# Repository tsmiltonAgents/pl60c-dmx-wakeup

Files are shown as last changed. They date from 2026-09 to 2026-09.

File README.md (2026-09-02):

# PL60C DMX wake-up lamp controller

A small ESP32-S3 board that drives the wired DMX512 input of a **Neewer PL60C** panel light so the
light can be ramped up slowly in the morning (sunrise alarm). Rev A, 2026-09-02.

Everything in this repository is generated by scripts (`./build.sh`): schematic, PCB, autorouting,
design-rule checks, Gerbers, and the JLCPCB BOM / pick-and-place files. The design passes KiCad ERC and
DRC with zero errors, the schematic and PCB netlists are cross-checked against the single source of
truth (`hw/design.py`), and every part number has been verified in stock on LCSC/JLCPCB.

| | |
|---|---|
| Board | 80 x 54 mm, 2 layers, 1.6 mm FR-4, all parts on the top side |
| MCU | ESP32-S3-WROOM-1-N16R8 (Wi-Fi + BLE, native USB) |
| DMX out | 5-pin XLR female (Neutrik NC5FAH) **and** a 3-way screw terminal for a pigtail |
| Power | USB-C, 5 V, 1 A resettable fuse, 3.3 V LDO |
| UI | RESET, BOOT, USER buttons, WS2812B RGB status LED, magnetic buzzer (alarm fallback) |
| Extras | I2C/GPIO expansion header (RTC, light sensor), UART0 header |
| Files to order | `production/pl60c_dmx_gerbers.zip`, `production/pl60c_dmx_bom_jlcpcb.csv`, `production/pl60c_dmx_cpl_jlcpcb.csv` |
| Mini variant | 38.5 x 29 mm, 4 layers, both sides, same circuit and pin map: see section 8 and `production_mini/` |

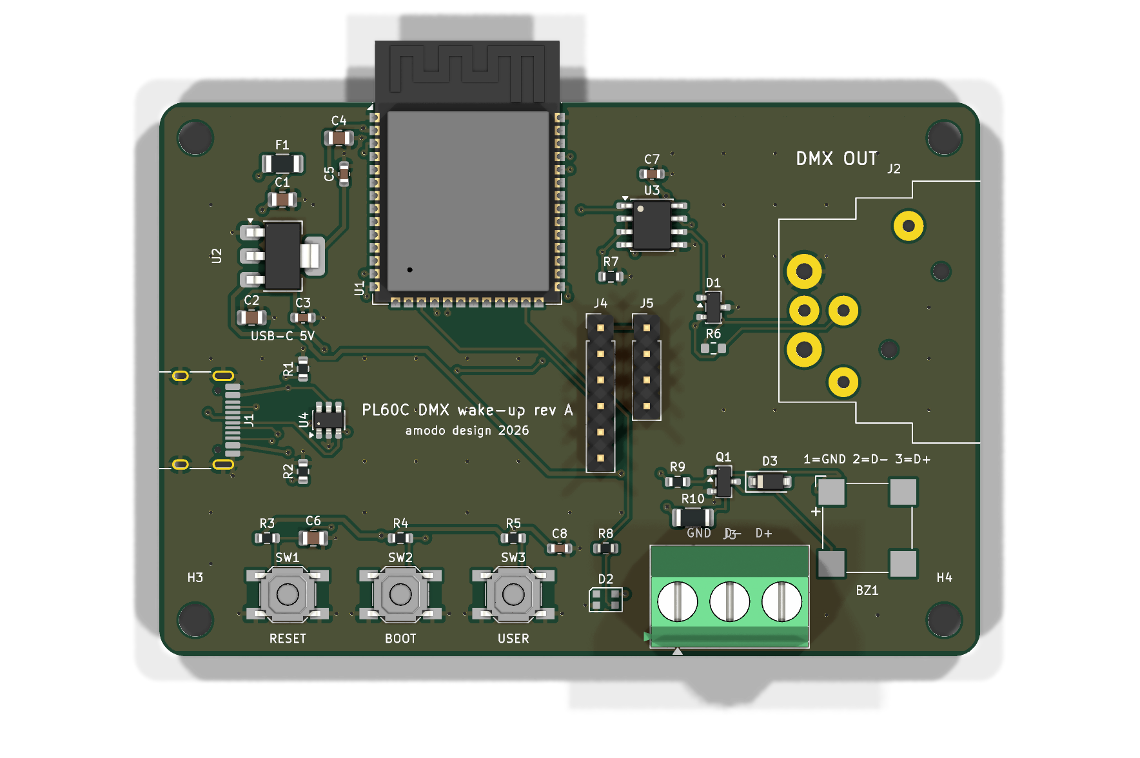
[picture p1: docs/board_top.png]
Board top


Status: **designed, reviewed and verified in software, not yet manufactured or bench-tested.** Read the
"Before you order" section and `docs/REVIEW.md` (design review: 3 wiring/spec bugs found and fixed).

---

## 1. How the light is controlled

### 1.1 The PL60C's DMX port (verified from Neewer's manual and DMX chart)

* Connectors on the bottom edge of the lamp head: `DMX-IN` = **5-pin XLR male** panel socket,
  `DMX-OUT` = 5-pin XLR female (pass-through for daisy-chaining).
* Pinout: pin 1 = signal common (0 V), pin 2 = Data−, pin 3 = Data+, pins 4 and 5 unused.
* Enable DMX on the light: long-press MODE/MENU, set `DMX ON/OFF` = ON, then `DMX ADDR` (001–512, default 1).
* On loss of the DMX signal the light **holds the last look** (no timeout). The controller must therefore
  keep streaming frames; when you want the light off, send intensity 0 rather than stopping the stream.
* No RDM support is documented. The port is not documented as isolated.

This board is the DMX **transmitter**, so it has a 5-pin XLR **female** socket (ANSI E1.11 convention).
A normal 5-pin DMX cable (male–female) goes from this board to the light's `DMX-IN`.

### 1.2 PL60C channel map (one fixed personality)

Channel numbers are relative to the DMX start address `n` set on the light. Channel `n` selects the mode,
`n+1` is always intensity, the rest depend on the mode. The FX mode uses up to 9 channels, so treat the
light as a 9-channel fixture.

| ch n value | Mode | n+1 | n+2 | n+3 | n+4 … n+8 |
|---|---|---|---|---|---|
| 0–31 | **CCT** | Intensity 0–100 % | Colour temperature 2500–10000 K | G/M −50…+50 | – |
| 32–63 | HSI | Intensity | Hue 0–360° | Saturation 0–100 % | – |
| 64–95 | FX | Intensity | Effect select | effect parameters | effect parameters |
| 96–127 | GEL | Intensity | Gel brand | Gel index | – |
| 128–159 | RGBCW | Intensity | Red | Green | Blue, Cool white, Warm white |
| 160–191 | XY | Intensity | x | y | – |

For a sunrise, CCT mode is the natural choice: ramp `n+1` from 0 to the target and, if you like, sweep
`n+2` from warm (2500 K) towards neutral as the intensity rises. Sources are listed at the end.

### 1.3 DMX512 on the wire

DMX512 is EIA-485 at 250 kbit/s, 8 data bits, no parity, 2 stop bits. A frame is: BREAK (≥ 92 µs, use
176 µs) → MARK-AFTER-BREAK (≥ 12 µs) → start code 0x00 → up to 512 slot bytes, then repeat at roughly
40–44 Hz. Data+ (pin 3) is the RS-485 **A** line, Data− (pin 2) is **B**, pin 1 is the common. A 120 Ω
terminator belongs only at the far end of the cable (the last fixture), never at the transmitter.

---

## 2. Hardware design

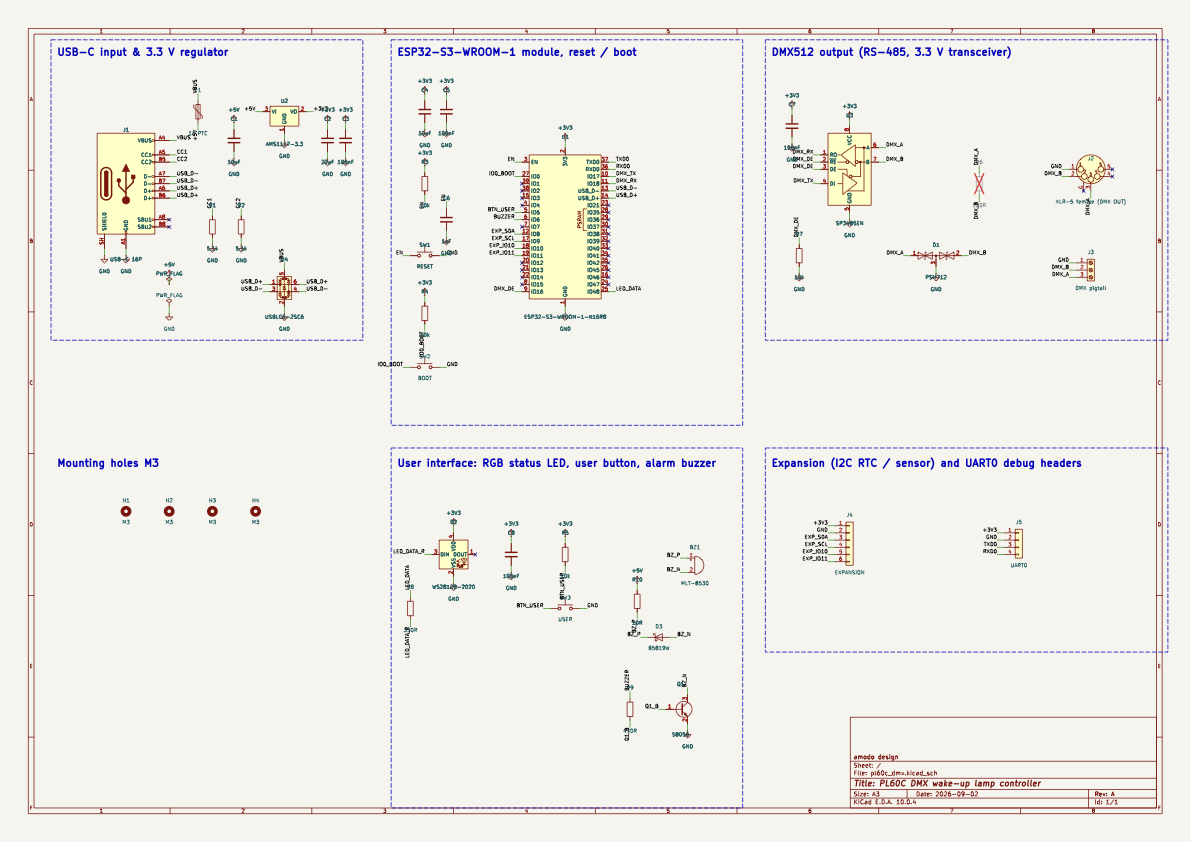
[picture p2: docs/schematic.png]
Schematic


Full-size PDF: `production/pl60c_dmx_schematic.pdf`.

### 2.1 Blocks

**USB-C input and 3.3 V rail.** 16-pin USB-C receptacle (HRO TYPE-C-31-M-12) with 5.1 kΩ CC pull-downs
so any USB-C charger or host supplies 5 V. A 1 A hold / 1.8 A trip PTC (F1) protects the board, a
USBLC6-2SC6 (U4) clamps ESD on D+/D−/VBUS, and an AMS1117-3.3 (U2, 1 A) makes 3.3 V with 10 µF on both
sides. Budget: ESP32-S3 Wi-Fi peaks ≈ 0.5 A, buzzer ≈ 0.1 A average, LED < 60 mA.

**ESP32-S3-WROOM-1-N16R8 (U1).** 16 MB flash, 8 MB PSRAM, on-module PCB antenna. The antenna end of the
module hangs 6 mm past the top board edge, which is Espressif's preferred placement (no copper anywhere
near the antenna). USB D+/D− go straight to GPIO20/GPIO19: the S3's built-in USB-Serial/JTAG gives
programming, console and debugging with no bridge chip. EN has the standard 10 kΩ + 1 µF reset delay and
the RESET button; GPIO0 has a 10 kΩ pull-up and the BOOT button (hold BOOT, tap RESET to force the
ROM downloader, or just use `esptool` over USB which does it automatically).

**DMX transmitter (U3, SP3485EN).** 3.3 V RS-485 half-duplex transceiver, pin-compatible with MAX3485.
DI ← GPIO17 (UART TX), RO → GPIO18 (UART RX), DE and /RE tied together to GPIO16 with a 10 kΩ pull-down,
so the line is only driven once firmware asserts DE (keeps the bus quiet during boot/flash). A → XLR
pin 3 (Data+), B → XLR pin 2 (Data−), XLR pin 1 → GND. A PSM712 asymmetric TVS array (D1, +12 V / −7 V,
the RS-485 standard part) clamps surges on both lines. R6 (120 Ω) is fitted **only** if you ever want this
board to terminate a line; it is marked DNP and JLCPCB will not place it. The same three signals are on
screw terminal J3 (GND, D−, D+) so you can wire a cable pigtail instead of using the XLR.

**User interface.** WS2812B-2020-V6 RGB LED (D2) on GPIO48 through 330 Ω, powered from 3.3 V (the V6
silicon is specified for 3.3 V supply, VIH = 0.55 VDD). USER button on GPIO5 with a 10 kΩ pull-up
(snooze / manual on). Magnetic buzzer BZ1 (MLT-8530, passive, 2.7 kHz resonant, 16 Ω) driven from the
5 V rail through a 10 Ω series resistor (R10, limits the coil to its 3.6 V rating) by an S8050 NPN (Q1,
SOT-23, base via 470 Ω from GPIO6) with a B5819W Schottky flyback diode (D3) across the coil.

**Expansion.** J4: 3V3, GND, GPIO8 (SDA), GPIO9 (SCL), GPIO10, GPIO11 (e.g. a DS3231 RTC or an ambient
light sensor). J5: 3V3, GND, GPIO43 (TXD0), GPIO44 (RXD0). Four M3 mounting holes.

### 2.2 Pin map (also in `firmware/pins.h`)

| Function | GPIO | Notes |
|---|---|---|
| DMX TX (SP3485 DI) | 17 | UART1 TX |
| DMX RX (SP3485 RO) | 18 | UART1 RX, only for RDM/monitoring |
| DMX DE / /RE | 16 | HIGH = transmit; 10 kΩ pull-down |
| USB D− / D+ | 19 / 20 | native USB-Serial/JTAG |
| BOOT button | 0 | active low, strapping pin |
| USER button | 5 | active low, 10 kΩ pull-up |
| WS2812B data | 48 | 330 Ω series, LED at 3.3 V |
| Buzzer | 6 | NPN low-side switch, PWM 2.7 kHz |
| I2C SDA / SCL | 8 / 9 | header J4 |
| Spare | 10 / 11 | header J4 |
| UART0 TX / RX | 43 / 44 | header J5 |

Unused module pins are left unconnected. GPIO35–37 are reserved by the octal PSRAM of the R8 module
and GPIO3/45/46 are strapping pins; none of them is used.

### 2.3 Layout

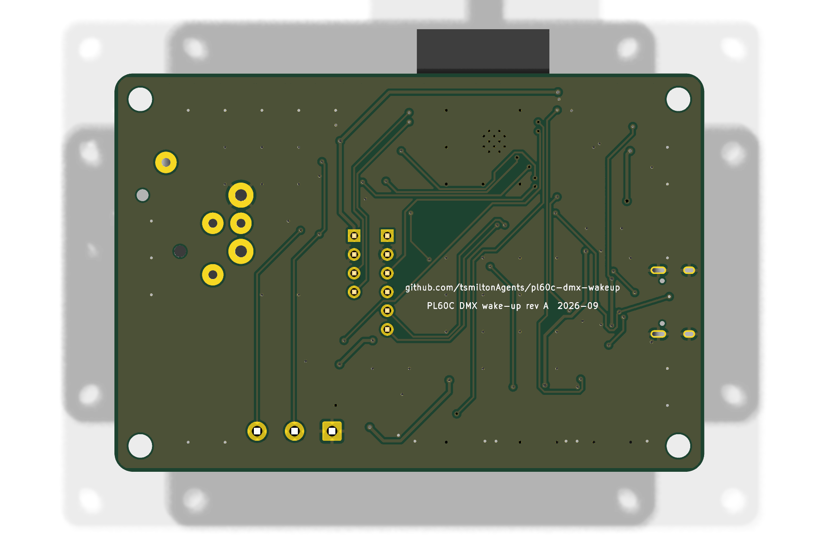
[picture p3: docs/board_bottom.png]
Board bottom


USB-C on the left edge, XLR on the right edge with its flange over the board edge, buttons and the LED
along the bottom edge for an enclosure front panel, the terminal block also on the bottom edge.
Ground pours on both layers with stitching vias, 0.25 mm signal tracks, 0.4 mm power tracks,
0.15 mm clearance, 0.7 / 0.35 mm vias: all comfortably inside JLCPCB's 2-layer capability.
The USB-C data-pair escape is hand-routed (the router cannot do the D+/D− pair swap at 0.5 mm pitch);
the rest is autorouted by Freerouting and then checked by KiCad DRC.

---

## 3. Firmware guidance (no firmware is included, by design)

The hardware was designed so that the standard **[esp_dmx](https://github.com/someweisguy/esp_dmx)**
library works unmodified: `dmx_set_pin(DMX_NUM_1, PIN_DMX_TX, PIN_DMX_RX, PIN_DMX_DE)` and then
`dmx_write()` + `dmx_send()` at 40–44 Hz. It handles the break/MAB timing with the UART hardware.

Suggested behaviour:

1. Boot, connect to Wi-Fi, sync time by SNTP (add a DS3231 on J4 if you want time without Wi-Fi).
2. Stream a DMX frame continuously (44 Hz). Idle: `ch1 = 0` (CCT mode), `ch2 = 0` (intensity 0).
   Never stop the stream: the PL60C holds the last look on signal loss.
3. Sunrise: over 20–30 min raise `ch2` from 0 → target with a perceptual (gamma ≈ 2.2) curve, optionally
   sweep `ch3` from 2500 K towards 4000–5600 K. After the ramp hold, then optionally sound the buzzer
   (2.7 kHz square wave on GPIO6, 50 % duty, short beeps) until USER is pressed.
4. USER button: short press = snooze / cancel, long press = manual light toggle. BOOT can be a second
   button after boot. RGB LED: breathing colours for state (idle / ramping / alarm / no Wi-Fi).
5. Set the light's `DMX ADDR` to 1 so the controller's channels 1–9 map directly.

Provisioning, OTA and a web UI are the usual ESP-IDF / Arduino-ESP32 fare; the S3's USB CDC console is
available on the USB-C port without any extra hardware.

---

## 4. Ordering from JLCPCB

Files in `production/`:

| File | Purpose |
|---|---|
| `pl60c_dmx_gerbers.zip` | Gerber RS-274X (Protel extensions) + Excellon drills, JLCPCB settings |
| `pl60c_dmx_bom_jlcpcb.csv` | BOM in JLCPCB format (Comment, Designator, Footprint, LCSC Part #) |
| `pl60c_dmx_cpl_jlcpcb.csv` | Pick-and-place, rotations corrected with the JLCKicadTools database |
| `pl60c_dmx_cpl_kicad_rotation.csv` | Same, with raw KiCad rotations, in case the preview shows parts turned |
| `pl60c_dmx_bom_full.csv` | Engineering BOM incl. DNP and mechanical parts |
| `pl60c_dmx_schematic.pdf`, `pl60c_dmx_pcb_top.pdf`, `pl60c_dmx_pcb_bottom.pdf`, `pl60c_dmx.step` | documentation / mechanical |

Steps:

1. jlcpcb.com → *Order now* → upload `pl60c_dmx_gerbers.zip`. Options: 2 layers, 80 x 54 mm, 1.6 mm,
   any colour, HASL (lead-free) or ENIG, 1 oz copper, "Remove order number: specify location" is not
   needed (no marker placed; choose "Yes" if you dislike the number).
2. Turn on **PCB Assembly**, top side, then upload `pl60c_dmx_bom_jlcpcb.csv` and
   `pl60c_dmx_cpl_jlcpcb.csv`.
3. In the parts step all 25 BOM lines resolve to the LCSC numbers below. R6 is intentionally absent (DNP).
4. **Check the placement preview carefully** for rotation of U2 (SOT-223), U3 (SOIC-8), D1/Q1 (SOT-23),
   J1 (USB-C), D2 (WS2812B), J2 (XLR) and J3 (terminal). JLCPCB's orientation conventions differ from
   KiCad's per package; if any polarised part looks turned, re-upload
   `pl60c_dmx_cpl_kicad_rotation.csv` or rotate it in their editor. Pin 1 of the module is the
   top-left pad when the antenna points up.
5. Through-hole parts (XLR, terminal block, headers) are "extended" parts assembled by hand at JLCPCB;
   they add a small per-part fee. If you prefer, delete J2/J3/J4/J5 from the BOM and solder them yourself.

### 4.1 Bill of materials (all verified in stock on LCSC on 2026-09-02, `tools/check_lcsc.py`)

| Ref | Part | LCSC | JLC type |
|---|---|---|---|
| U1 | ESP32-S3-WROOM-1-N16R8 | C2913202 | extended |
| U2 | AMS1117-3.3, SOT-223 | C6186 | basic |
| U3 | SP3485EN-L/TR, SOIC-8 | C8963 | basic |
| U4 | USBLC6-2SC6, SOT-23-6 | C7519 | extended |
| D1 | PSM712-LF-T7 TVS, SOT-23 | C32677 | basic |
| D2 | WS2812B-2020-V6 RGB LED | C52917434 | extended |
| D3 | B5819W Schottky, SOD-123 | C8598 | basic |
| Q1 | S8050 NPN, SOT-23 (B-E-C) | C2146 | basic |
| F1 | PTC 1 A hold, 1206 | C5358568 | extended |
| J1 | USB-C 16P, HRO TYPE-C-31-M-12 | C165948 | extended |
| J2 | Neutrik NC5FAH XLR-5 female, PCB horizontal | C368501 | extended (low stock, ~130) |
| J3 | KF128-5.08-3P screw terminal | C474953 | extended |
| J4 / J5 | 2.54 mm headers 1x6 / 1x4 | C37208 / C124378 | extended |
| SW1–SW3 | TS-1187A-B-A-B tactile 5.1 mm | C318884 | basic |
| BZ1 | MLT-8530 magnetic buzzer | C94599 | extended |
| C1, C4 | 10 µF 25 V 0805 | C15850 | basic |
| C2 | 22 µF 25 V 0805 | C45783 | basic |
| R10 | 10 Ω 1206 250 mW | C17903 | basic |
| C6 | 1 µF 50 V 0805 | C28323 | basic |
| C3, C5, C7, C8 | 100 nF 50 V 0603 | C14663 | basic |
| R1, R2 | 5.1 kΩ 0603 | C23186 | basic |
| R3, R4, R5, R7 | 10 kΩ 0603 | C25804 | basic |
| R8 | 330 Ω 0603 | C23138 | basic |
| R9 | 470 Ω 0603 | C23179 | basic |
| R6 | 120 Ω 0603, **DNP** | C22787 | – |

If the NC5FAH is out of stock: CAX **XLR-5M-24WP** (C53431204, same NC5FAH footprint, female despite the
name) or order the Neutrik separately and hand-solder it. Rough parts cost per board is about USD 15
(ESP32 ≈ 5, XLR ≈ 6), plus JLCPCB's PCB and assembly fees.

### 4.2 Before you order

* This is a rev A that has only been verified by simulation-free checks (ERC, DRC, netlist, Gerber
  review, part stock). The circuit follows Espressif's and the transceiver vendor's reference designs
  closely, but a first build should be treated as a prototype.
* The DMX port is **not galvanically isolated** (same as most hobby DMX interfaces). The PL60C runs from
  its own 19.6 V PSU; keep the controller on a separate USB supply and you have a normal
  ground-referenced link, which is how the light's own wired console connection works. An isolated
  variant (ADM2483 + B0505S) would add ~USD 7 and a second transceiver footprint; not done in rev A.
* USB-C receptacle mechanical: the connector body is placed with its front lip 0.55 mm proud of the
  board edge, per the HRO drawing. Check it against your enclosure.

---

## 5. Hooking it up

1. Flash firmware over the USB-C port (native USB, no driver hassle on macOS/Linux).
2. Cable: 5-pin XLR male → female DMX cable from this board's `DMX OUT` to the light's `DMX-IN`.
   Or wire a cable to J3: `GND` → XLR pin 1, `D−` → pin 2, `D+` → pin 3.
3. On the light: `DMX ON`, `DMX ADDR = 001`.
4. If the light is the only fixture and the cable is longer than a few metres, fit a 120 Ω terminator
   plug in the light's `DMX-OUT`. Do not fit R6 on this board.

---

## 6. What was verified

| Check | Result |
|---|---|
| Design review against datasheets (`docs/REVIEW.md`) | 14 items; 3 bugs found and fixed (SOT-23 transistor pinout, LED supply spec, buzzer overdrive) |
| KiCad ERC on the generated schematic | 0 findings |
| Schematic netlist vs `hw/design.py` | 27/27 nets identical |
| PCB pad-to-net vs `hw/design.py` | 27/27 nets identical |
| KiCad DRC (clearance 0.15 mm, edge 0.3 mm, hole-to-hole 0.5 mm, courtyards, silkscreen) | 0 errors; 6 warnings, all "silkscreen clipped by board edge" from the three connectors that deliberately overhang the edge |
| Unrouted connections | 0 |
| Gerbers rendered independently with gerbv (copper, silk, mask, paste, outline, drills) | match the KiCad board, see `docs/gerber_*_check.png` |
| Drill file | 151 plated + 8 non-plated holes, smallest 0.30 mm (module thermal vias enlarged from the library's 0.2 mm to suit JLCPCB) |
| LCSC stock / package for every part number | all in stock, packages match footprints (`tools/check_lcsc.py`) |
| Datasheets checked against footprints | TS-1187A vs Alps SKQG land pattern, MLT-8530 pad layout, KF128 pin size (holes set to 1.4 mm), NC5FAH (KiCad footprint is for this exact part) |

---

## 7. Repository layout and regenerating

```
hw/design.py        single source of truth: parts, LCSC numbers, nets, schematic and PCB placement
hw/design_mini.py   the MINI variant (same circuit, different parts/placement); hw/variant.py selects it
hw/gen_sch.py       KiCad 10 schematic writer (labels + power symbols, ERC-clean)
hw/gen_pcb.py       pcbnew script: board outline, footprints, nets, rules, pours, GND stitching, USB escape
hw/route.py         Freerouting driver (DSN export, autoroute, SES import, zone fill)
hw/fix_gnd.py       post-route ground fixer + dangling via cleanup
tools/export.py     Gerbers/drill, JLCPCB BOM + CPL, PDFs, renders, STEP
tools/verify_*.py   netlist consistency checks
tools/check_lcsc.py live stock check of every LCSC part number
pcb/                the generated KiCad project (open pl60c_dmx.kicad_pro in KiCad 10)
production/         everything JLCPCB needs
docs/               images used in this README
firmware/pins.h     pin map and DMX constants for the firmware author
build.sh            full pipeline; autocommit.sh commits and pushes every 2 minutes
```

Regenerate with `./build.sh` (rev A) or `./build.sh mini`. Requirements: KiCad 10.0.x app bundle at `/Applications/KiCad`
(its bundled Python is used for `pcbnew`), Java 25+ (`brew install openjdk`) and
`tools/freerouting.jar` (Freerouting 2.3.0, download from its GitHub releases), plus `gerbv` if you want
the Gerber check images. Edit `hw/design.py`, never the KiCad files (they are overwritten).

---

## 8. MINI variant (38.5 x 29 mm, 4 layers, both sides)

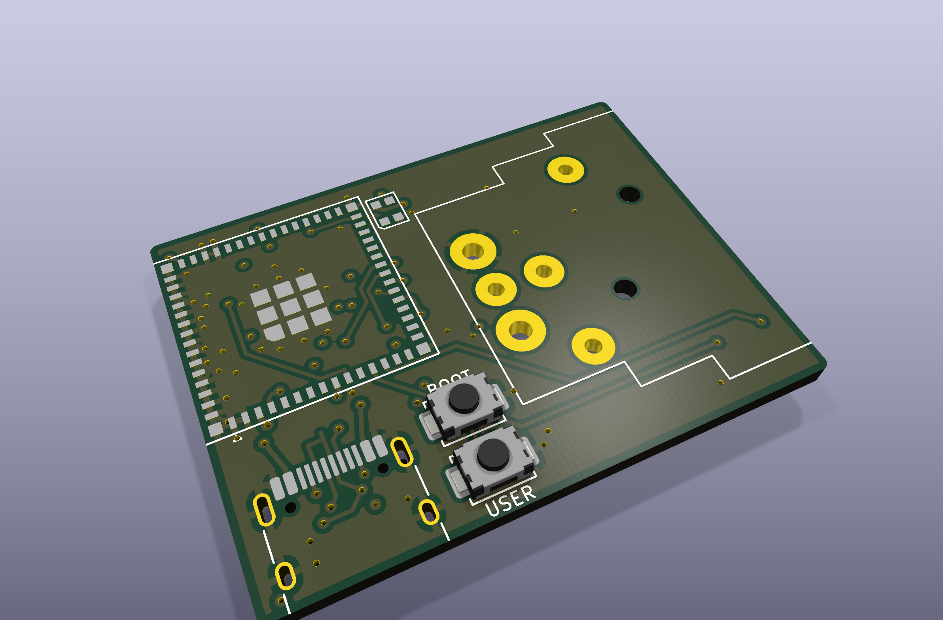
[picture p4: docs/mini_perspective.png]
Mini board


Same circuit, same GPIO map, one quarter of the area (1120 mm² vs 4320 mm²). Files: `production_mini/`
(`pl60c_dmx_mini_gerbers.zip`, `pl60c_dmx_mini_bom_jlcpcb.csv`, `pl60c_dmx_mini_cpl_jlcpcb.csv`),
KiCad project `pcb/pl60c_dmx_mini.*`, source `hw/design_mini.py`, build with `./build.sh mini`.

What changed to get there:

| | rev A | mini |
|---|---|---|
| Module | ESP32-S3-WROOM-1-N16R8 (18 x 25.5 mm) | **ESP32-S3-MINI-1-N8** (15.4 x 20.5 mm, C2913206), antenna off the left edge |
| Layers / sides | 2 layers, top only | **4 layers** (JLC04161H-7628 stack: signal, solid GND plane, signal + GND pour, signal), parts on **both sides** |
| XLR-5 female | on board | **on board** (Neutrik NC5FAH, right edge; its flange holes mount the board) |
| Passives | 0603 / 0805 | **0402** (all JLCPCB Basic), 10 µF in 0603 |
| LDO | AMS1117 SOT-223 | **AP2112K-3.3** SOT-23-5, 600 mA (C51118) |
| RGB LED | WS2812B-2020-V6 | same |
| Buttons | RESET, BOOT, USER (5.1 mm) | **BOOT, USER** (3.9 x 3 mm TS-1088, Basic); reset = re-plug USB or EN via the 10 k/1 µF network |
| Buzzer | on board | **off board**: driver kept (S8050 + 10 Ω + flyback), solder a passive magnetic buzzer to the `BZ+`/`BZ-` pads |
| Pigtail terminal, headers, mounting holes | yes | dropped; I2C expansion on 4 test pads (`3V3 GND SDA SCL`), UART0 not brought out (USB console) |
| PTC | 1 A 1206 | same |

Top side: module, USB-C, XLR, two buttons, RGB LED. Bottom side: everything else. The USB-C body
protrudes 0.55 mm from the bottom edge, the XLR flange protrudes from the right edge, and the module
antenna hangs 4.5 mm off the left edge, so the enclosure needs cut-outs on three sides.

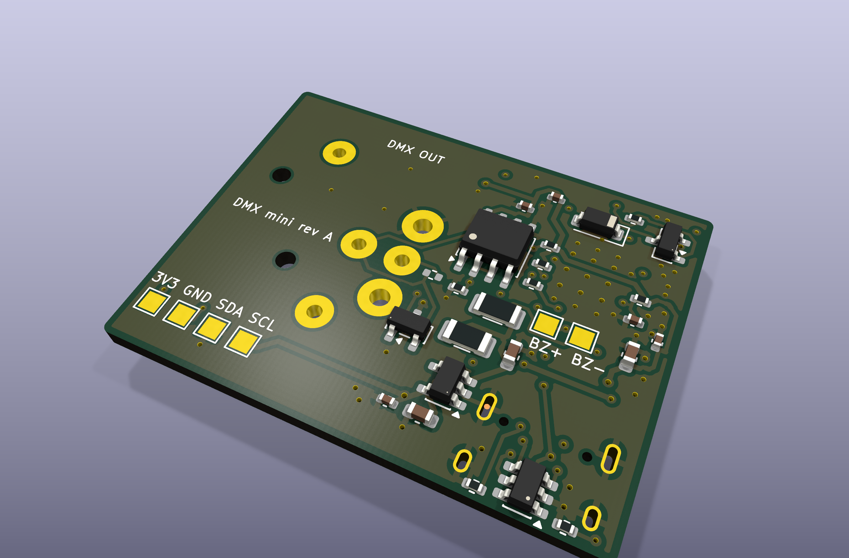
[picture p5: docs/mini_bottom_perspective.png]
Mini bottom


Verification, same procedure as rev A: ERC 0 findings, schematic and PCB netlists identical to the design
(23 nets), 0 unrouted, DRC 0 errors (6 "silkscreen clipped by edge" warnings from the overhanging parts
and one dangling stub warning inside the hand-routed USB escape), Gerbers for all four copper layers
rendered and checked with gerbv (`docs/mini_gerber_*_check.png`), every LCSC part in stock
(`PL60C_VARIANT=mini python3 tools/check_lcsc.py`). JLCPCB rules used: 0.1 mm min track/clearance
(4-layer capability is 0.09 mm), 0.3 mm min via drill, 0.5 mm hole-to-hole, vias in the module's
centre ground pads as in Espressif's reference layout.

JLCPCB ordering differences: choose **4 layers**, and **both-side assembly** (higher setup fee) or, to save
money, top-side assembly only and hand-solder the bottom (0402s are fiddly; not recommended).
The KiCad library has no 3D model for the MINI-1 module, so it is missing from the renders (its land
pattern is the 15.4 x 20.5 mm outline top-left). `pl60c_dmx_mini_cpl_jlcpcb.csv` marks bottom parts as
`Bottom`; JLCPCB mirrors bottom-side X automatically, check their preview.

## Sources

* Neewer PL60C manual (menu, DMX pinout, hold-on-loss): https://www.manua.ls/neewer/pl60c/manual
* Neewer PL60C official DMX channel table (PDF): https://usdb.oss-us-west-1.aliyuncs.com/neewer_support/instruction/PL60C%20摄影灯DMX列表-en.pdf
* Connector photos (Amazon listing B0CJY2WXMP), Showsync / Enttec forum threads on the PL60C profile
* ANSI E1.11 DMX512-A timing; SP3485, PSM712, AMS1117, ESP32-S3-WROOM-1 datasheets; Espressif ESP32-S3-DevKitC-1 schematic

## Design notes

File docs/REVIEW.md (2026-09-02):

# Design review (senior EE pass), 2026-09-02

Scope: rev A (`hw/design.py`) and MINI (`hw/design_mini.py`). Method: every pin mapping checked against the
LCSC-hosted datasheet of the exact ordered part, not the KiCad symbol; supply/thermal/drive margins
calculated; manufacturing rules re-checked against JLCPCB capability. Findings are ordered by severity.
Everything marked **fixed** is in the current files and both boards were rebuilt and re-verified
(ERC 0, netlist match, DRC 0 errors, stock check) after the fixes.

| # | Sev | Finding | Evidence | Status |
|---|---|---|---|---|
| 1 | **Critical** | Buzzer transistor Q1 (S8050, SOT-23) was wired with KiCad's *TO-92* S8050 symbol (E-B-C = 1-2-3). The ordered SOT-23 part (C2146, marking J3Y) is **B-E-C = 1-2-3**. As built, GPIO drove the emitter and the base sat on GND: buzzer would never sound, and the base-emitter junction would be reverse-biased to 3.3 V (VEBO 5 V, survives, but wrong). | C2146 datasheet p.1 pin diagram | **Fixed**: symbol changed to the SOT-23 B-E-C symbol (`Transistor_BJT:BC817` with value S8050), nets pad1=base, pad2=GND, pad3=collector. Both boards. |
| 2 | Major | Rev A RGB LED WS2812B-B/T (5050, C2761795) run from 3.3 V: datasheet VDD 3.7–5.3 V, VIH 2.7 V min. Would usually work, but out of spec on two parameters. | C2761795 datasheet, "Power supply voltage +3.7~+5.3 V", "VIH 2.7 V" | **Fixed**: both boards now use WS2812B-2020-V6 (C52917434), whose datasheet states VDD +3.3 to +5.3 V, VIH 0.55·VDD, "supports a 3.3 V power supply". |
| 3 | Major | Buzzer MLT-8530 driven straight from 5 V: rated 3.6 V, operating 2.5–4.5 Vo-p; coil 16 Ω → ~290 mA peaks, above the 95 mA rated. | C94599 datasheet p.2 | **Fixed**: 10 Ω 1206 (C17903, 250 mW) in series (R10): ~180 mA peak, 2.9 V across the coil, 0.16 W in the resistor at 50 % duty. Base resistor 1 kΩ → 470 Ω (datasheet drive circuit; forced β ≈ 35 with hFE ≥ 120). Mini: R10 is on board, buzzer external on BZ+/BZ−. |
| 4 | Major | MINI LDO AP2112K-3.3 (SOT-23-5) thermal: θJA 184 °C/W. Continuous Wi-Fi TX average ≈ 0.3 A × 1.7 V = 0.5 W → +92 °C; in a warm enclosure this approaches the 150 °C junction / 160 °C shutdown. Normal wake-up-lamp duty (modem sleep, short bursts) is 50–150 mA → +15–45 °C, fine. | C51118 datasheet, thermal table; ESP32-S3 datasheet current figures | **Open, mitigated**: the GND pad has a stitching via into the ground plane; firmware must keep Wi-Fi power-save on and avoid long continuous TX (OTA at night is fine). If the firmware needs sustained full-power Wi-Fi, use rev A (AMS1117, 1 A, SOT-223) or a buck. Documented in README/pins.h. |
| 5 | Minor | AMS1117 (rev A) output capacitor: datasheet asks for ≥ 22 µF; design had 10 µF. Ceramic 10 µF works on countless boards, but no reason to run below the datasheet value. | AMS1117 datasheet | **Fixed**: C2 = 22 µF 0805 (C45783). |
| 6 | Minor | MINI PTC 0805 0.75 A hold, 6 V: hold current derates ~20 % at 50 °C and Wi-Fi peaks (0.5 A) + LED + buzzer can approach it. | Littelfuse 0805L derating curves | **Fixed**: MINI now uses the same 1 A / 1.8 A 1206 PTC as rev A (C5358568). |
| 7 | Minor | MINI 3V3 decoupling (C4 10 µF, C5 100 nF) was ~14 mm from module pin 3. | Espressif hardware design guidelines: decoupling close to 3V3 pin | **Fixed**: C4/C5 now sit on the bottom directly under module pin 3 (2 mm away, via to the plane). |
| 8 | Minor | SP3485 RO output is high-impedance whenever DE=1 (DE and /RE are tied), so GPIO18 floats while transmitting. | SP3485 datasheet | **Documented**: firmware enables the GPIO18 internal pull-up (or ignores RX). No hardware change; a 10 k pull-up can be added on rev A's spare area if RDM is ever used. |
| 9 | Info | I2C expansion (GPIO8/9) has no on-board pull-ups. | — | Documented: pull-ups belong on the peripheral board; ESP32 internal pull-ups (~45 k) suffice for short wires at 100 kHz. |
| 10 | Info | DMX port is not galvanically isolated; XLR shell (pad G) left floating. | ANSI E1.11 allows non-isolated for short local links | Documented (README). Fit an isolated variant if the light is on a different mains circuit far away. |
| 11 | Info | JLCPCB rotation convention for polarised parts differs from KiCad; MINI bottom-side parts additionally mirrored. | — | Documented: check the JLCPCB placement preview; two CPL files provided. |
| 12 | Info | ESP32-S3 strapping: GPIO0 pulled up + button; GPIO3/45/46 left floating as Espressif allows (internal pull defaults select normal boot); EN 10 k + 1 µF. USB D+/D− direct to GPIO20/19 (native USB-Serial/JTAG needs no external parts). | ESP32-S3 datasheet §strapping pins; MINI-1 datasheet pin table (pins 3, 4, 9, 10, 12, 13, 20–24, 30, 45 verified) | OK |
| 13 | Info | RS-485 polarity: SP3485 A (pin 6) → XLR pin 3 (Data+), B (pin 7) → XLR pin 2 (Data−), XLR pin 1 → GND. PSM712 pin 3 = common (datasheet: "for 12 V, pins 1 and 2 are positive"). USB-C: 5.1 k CC pull-downs, USBLC6 pairs 1↔6 / 3↔4, VBUS on pin 5. | datasheets | OK |
| 14 | Info | MINI land pattern: KiCad `ESP32-S2-MINI-1` footprint vs ESP32-S3-MINI-1 datasheet figure 10: 60 × 0.4 × 0.8 pads at 0.85 mm, 4 × 0.8 corner pads, 3 × 3 centre pads 1.2 mm at 1.65 mm with thermal vias, 15.4 × 20.5 mm, pin 1 top-left below the antenna. | MINI-1 datasheet p.30 | OK (identical) |

## Margins checked

* 5 V rail: USB-C source ≥ 0.5 A (CC pull-downs advertise default USB), PTC 1 A hold. Load: ESP32-S3 peak 0.5 A
  for ms bursts, average 0.05–0.25 A; LED ≤ 0.06 A; buzzer 0.09 A average. OK.
* 3.3 V rail: rev A AMS1117 1 A, dropout 1.1–1.3 V from 4.8 V (after PTC) → fine. MINI: see #4.
* Reset: EN RC 10 ms. GPIO0 10 k pull-up. USB-Serial/JTAG can reset/boot the chip without buttons.
* DMX drive: SP3485 differential output ≥ 1.5 V into 27 Ω (two terminators); TVS PSM712 +12/−7 V; common-mode −7…+12 V.
* Buzzer driver: Ib 5.1 mA, Ic 180 mA, forced β 35 (hFE min 120 at 50 mA); flyback B5819W 1 A.
* PCB: rev A 0.25/0.15 mm track/clearance, 0.7/0.3 vias; MINI 0.25/0.15 (0.1 min), 0.7/0.3 vias, 0.5 mm
  hole-to-hole; both inside JLCPCB standard capability. GND stitching and inner planes verified by DRC
  connectivity (0 unconnected items).

## Still recommended before a production run

1. Build one, measure 3V3 ripple during Wi-Fi TX and the LDO temperature (MINI).
2. Scope the DMX output with the light connected: BREAK ≥ 92 µs, MAB ≥ 12 µs, 250 kbaud, ≥ 40 Hz refresh.
3. Confirm the PL60C actually accepts the frame (mode channel 0 = CCT, intensity on channel 2).

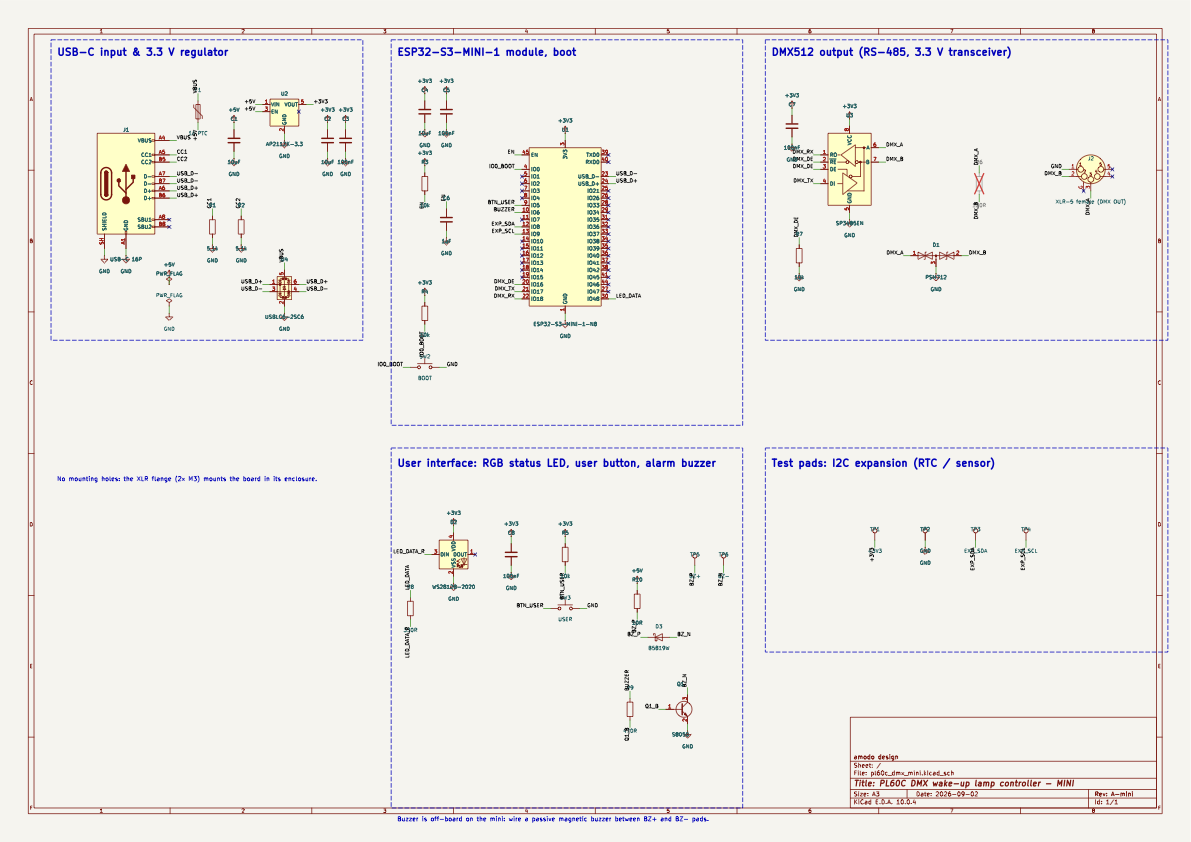
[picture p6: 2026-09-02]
docs/schematic_mini.png

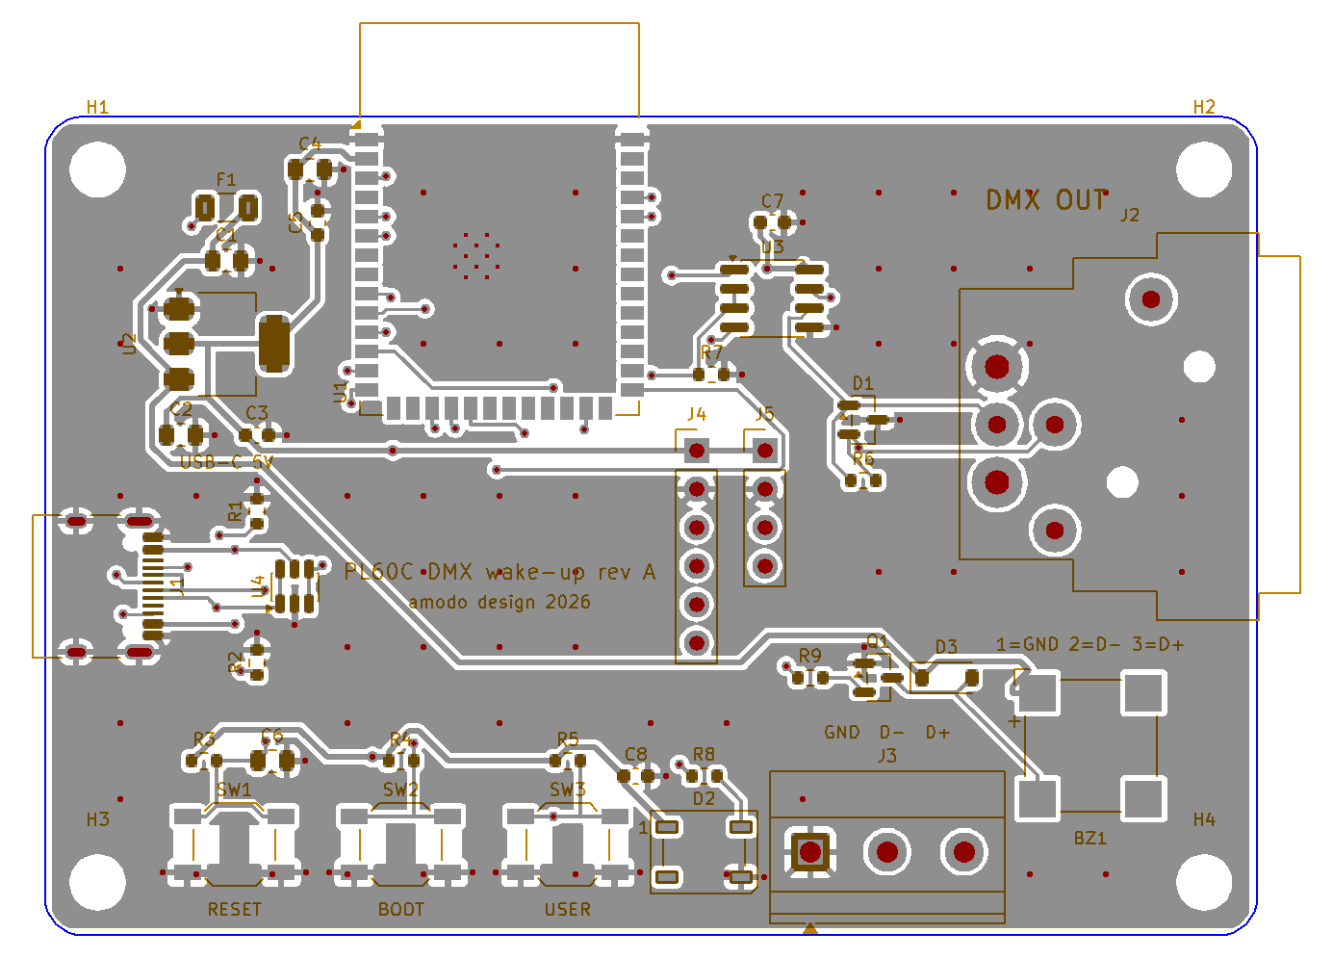
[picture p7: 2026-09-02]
docs/gerber_top_check.png

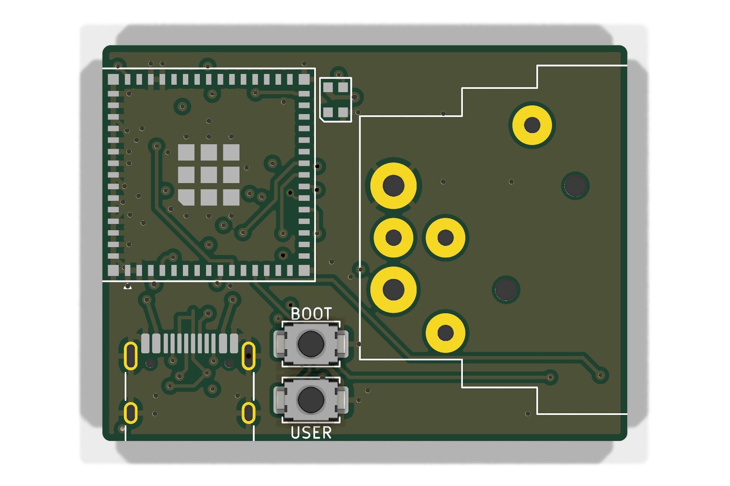
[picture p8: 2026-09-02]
docs/mini_top.png

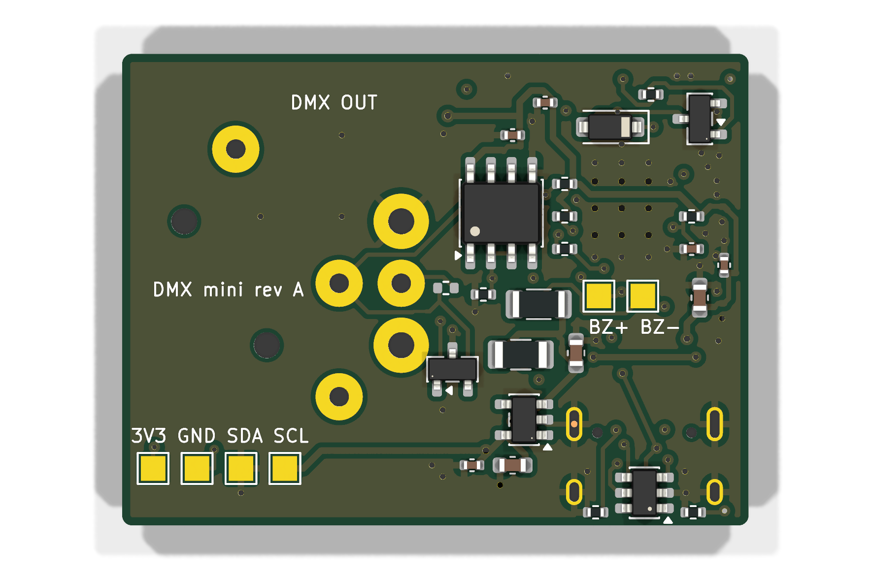
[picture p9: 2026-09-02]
docs/mini_bottom.png

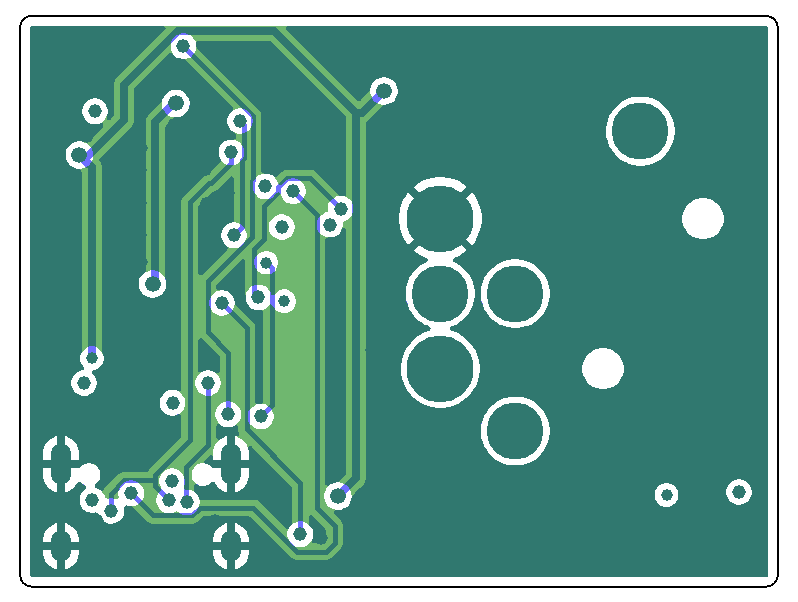
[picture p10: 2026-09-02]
docs/mini_gerber_inner_check.png

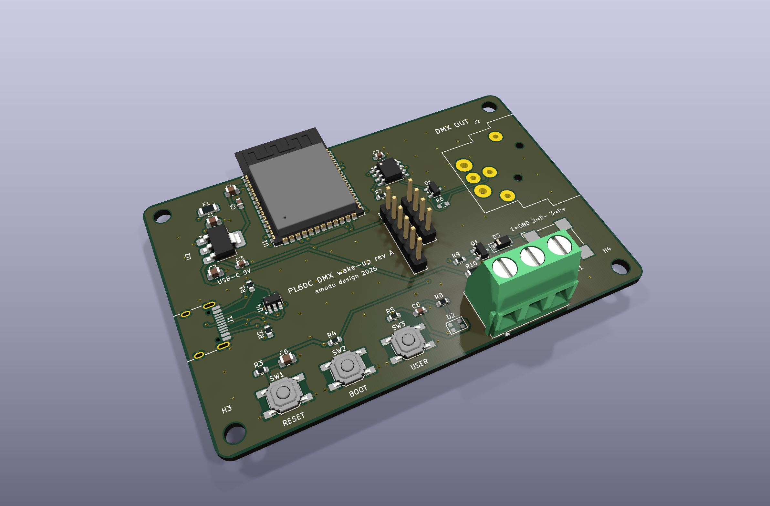
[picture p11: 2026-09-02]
docs/board_perspective.png

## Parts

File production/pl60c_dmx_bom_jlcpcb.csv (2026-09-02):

Comment | Designator | Footprint | LCSC Part #
MLT-8530 | BZ1 | MagneticBuzzer_CUI_CMT-8504-100-SMT | C94599
22uF | C2 | C_0805_2012Metric | C45783
10uF | C1,C4 | C_0805_2012Metric | C15850
1uF | C6 | C_0805_2012Metric | C28323
100nF | C3,C5,C7,C8 | C_0603_1608Metric | C14663
PSM712 | D1 | SOT-23 | C32677
WS2812B-2020 | D2 | LED_WS2812B-2020_PLCC4_2.0x2.0mm | C52917434
B5819W | D3 | D_SOD-123 | C8598
1A PTC | F1 | Fuse_1206_3216Metric | C5358568
USB-C 16P | J1 | USB_C_Receptacle_HRO_TYPE-C-31-M-12 | C165948
XLR-5 female (DMX OUT) | J2 | Jack_XLR_Neutrik_NC5FAH_Horizontal | C368501
DMX pigtail | J3 | TerminalBlock_Phoenix_MKDS-1,5-3-5.08_1x03_P5.08mm_Horizontal | C474953
EXPANSION | J4 | PinHeader_1x06_P2.54mm_Vertical | C37208
UART0 | J5 | PinHeader_1x04_P2.54mm_Vertical | C124378
S8050 | Q1 | SOT-23 | C2146
5.1k | R1,R2 | R_0603_1608Metric | C23186
10R | R10 | R_1206_3216Metric | C17903
10k | R3,R4,R5,R7 | R_0603_1608Metric | C25804
330R | R8 | R_0603_1608Metric | C23138
470R | R9 | R_0603_1608Metric | C23179
RESET | SW1 | SW_SPST_SKQG_WithStem | C318884
BOOT | SW2 | SW_SPST_SKQG_WithStem | C318884
USER | SW3 | SW_SPST_SKQG_WithStem | C318884
ESP32-S3-WROOM-1-N16R8 | U1 | ESP32-S3-WROOM-1 | C2913202
AMS1117-3.3 | U2 | SOT-223-3_TabPin2 | C6186
SP3485EN | U3 | SOIC-8_3.9x4.9mm_P1.27mm | C8963
USBLC6-2SC6 | U4 | SOT-23-6 | C7519

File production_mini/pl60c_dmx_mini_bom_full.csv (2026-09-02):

Ref | Value | MPN | LCSC | Footprint | DNP | Description
C1 | 10uF |  | C19702 | Capacitor_SMD:C_0603_1608Metric |  | 10uF 10V X5R 0603
C2 | 10uF |  | C19702 | Capacitor_SMD:C_0603_1608Metric |  | 10uF 10V X5R 0603
C3 | 100nF |  | C1525 | Capacitor_SMD:C_0402_1005Metric |  | 100nF 16V X7R 0402
C4 | 10uF |  | C19702 | Capacitor_SMD:C_0603_1608Metric |  | 10uF 10V X5R 0603
C5 | 100nF |  | C1525 | Capacitor_SMD:C_0402_1005Metric |  | 100nF 16V X7R 0402
C6 | 1uF |  | C52923 | Capacitor_SMD:C_0402_1005Metric |  | 1uF 25V X5R 0402 (EN reset delay)
C7 | 100nF |  | C1525 | Capacitor_SMD:C_0402_1005Metric |  | 100nF 16V X7R 0402
C8 | 100nF |  | C1525 | Capacitor_SMD:C_0402_1005Metric |  | 100nF 16V X7R 0402
D1 | PSM712 | PSM712-LF-T7 | C32677 | Package_TO_SOT_SMD:SOT-23 |  | RS-485 TVS array +12/-7 V SOT-23
D2 | WS2812B-2020 | WS2812B-2020-V6 | C52917434 | LED_SMD:LED_WS2812B-2020_PLCC4_2.0x2.0mm |  | Addressable RGB LED 2x2 mm (powered from 3V3 as on Espressif devkits)
D3 | B5819W | B5819W SL | C8598 | Diode_SMD:D_SOD-123 |  | Schottky flyback diode SOD-123
F1 | 1A PTC | BSMD1206-100-30V | C5358568 | Fuse:Fuse_1206_3216Metric |  | PTC resettable fuse 1206, 1 A hold / 1.8 A trip
J1 | USB-C 16P | TYPE-C-31-M-12 | C165948 | Connector_USB:USB_C_Receptacle_HRO_TYPE-C-31-M-12 |  | USB-C receptacle 16P, USB 2.0 (HRO TYPE-C-31-M-12)
J2 | XLR-5 female (DMX OUT) | NC5FAH | C368501 | Connector_Audio:Jack_XLR_Neutrik_NC5FAH_Horizontal |  | Neutrik XLR 5-pin female, horizontal PCB mount (DMX OUT)
Q1 | S8050 | S8050 | C2146 | Package_TO_SOT_SMD:SOT-23 |  | NPN 0.5A SOT-23 buzzer driver
R1 | 5.1k |  | C25905 | Resistor_SMD:R_0402_1005Metric |  | 5.1k 0402 1% (USB-C CC pull-down)
R2 | 5.1k |  | C25905 | Resistor_SMD:R_0402_1005Metric |  | 5.1k 0402 1% (USB-C CC pull-down)
R3 | 10k |  | C25744 | Resistor_SMD:R_0402_1005Metric |  | 10k 0402
R4 | 10k |  | C25744 | Resistor_SMD:R_0402_1005Metric |  | 10k 0402
R5 | 10k |  | C25744 | Resistor_SMD:R_0402_1005Metric |  | 10k 0402
R6 | 120R |  | C25079 | Resistor_SMD:R_0402_1005Metric | yes | 120R termination - DNP
R7 | 10k |  | C25744 | Resistor_SMD:R_0402_1005Metric |  | 10k 0402 (DE pull-down)
R8 | 330R |  | C25104 | Resistor_SMD:R_0402_1005Metric |  | 330R 0402 series (WS2812 data)
R9 | 470R |  | C25117 | Resistor_SMD:R_0402_1005Metric |  | 470R 0402 base resistor
R10 | 10R |  | C17903 | Resistor_SMD:R_1206_3216Metric |  | 10R 1206 250mW buzzer series resistor
SW2 | BOOT | TS-1088-AR02016 | C720477 | Button_Switch_SMD:SW_SPST_TS-1088-xR020 |  | Tactile switch 3.9x3x2 mm SMD
SW3 | USER | TS-1088-AR02016 | C720477 | Button_Switch_SMD:SW_SPST_TS-1088-xR020 |  | Tactile switch 3.9x3x2 mm SMD (snooze / manual on)
TP1 | +3V3 |  |  | TestPoint:TestPoint_Pad_1.5x1.5mm |  | Test pad 1.5 mm
TP2 | GND |  |  | TestPoint:TestPoint_Pad_1.5x1.5mm |  | Test pad 1.5 mm
TP3 | EXP_SDA |  |  | TestPoint:TestPoint_Pad_1.5x1.5mm |  | Test pad 1.5 mm
TP4 | EXP_SCL |  |  | TestPoint:TestPoint_Pad_1.5x1.5mm |  | Test pad 1.5 mm
TP5 | BZ+ |  |  | TestPoint:TestPoint_Pad_1.5x1.5mm |  | External buzzer pad (+5V via 10R)
TP6 | BZ- |  |  | TestPoint:TestPoint_Pad_1.5x1.5mm |  | External buzzer pad (driver collector)
U1 | ESP32-S3-MINI-1-N8 | ESP32-S3-MINI-1-N8 | C2913206 | RF_Module:ESP32-S2-MINI-1 |  | ESP32-S3 module 15.4x20.5 mm, 8 MB flash, PCB antenna (same land pattern as ESP32-S2-MINI-1)
U2 | AP2112K-3.3 | AP2112K-3.3TRG1 | C51118 | Package_TO_SOT_SMD:SOT-23-5 |  | LDO 3.3V 600mA SOT-23-5
U3 | SP3485EN | SP3485EN-L/TR | C8963 | Package_SO:SOIC-8_3.9x4.9mm_P1.27mm |  | RS-485 transceiver 3.3 V half-duplex SOIC-8
U4 | USBLC6-2SC6 | USBLC6-2SC6 | C7519 | Package_TO_SOT_SMD:SOT-23-6 |  | USB ESD protection array

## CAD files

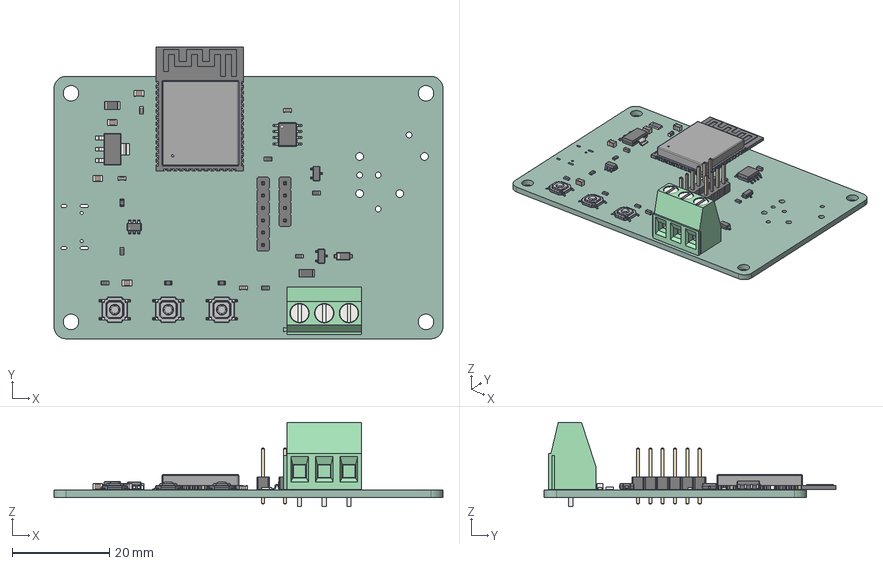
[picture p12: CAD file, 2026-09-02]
production/pl60c_dmx.step
80.0 x 60.0 x 17.3 mm
R_0603_1608Metric x 9
D_SOD-123
SOT-23 x 2
SOT-23-6
C_0805_2012Metric x 4
PinHeader_1x06_P254mm_Vertical
C_0603_1608Metric x 4
TerminalBlock_Phoenix_MKDS-1,5-3-5.08_1x03_P5.08mm_Horizontal
ESP32-S3-WROOM-1
SOIC-8_3.9x4.9mm_P1.27mm
R_1206_3216Metric
SW_SPST_SKQG_WithStem x 3
SOT-223
PinHeader_1x04_P254mm_Vertical
Fuse_1206_3216Metric
pl60c_dmx_PCB

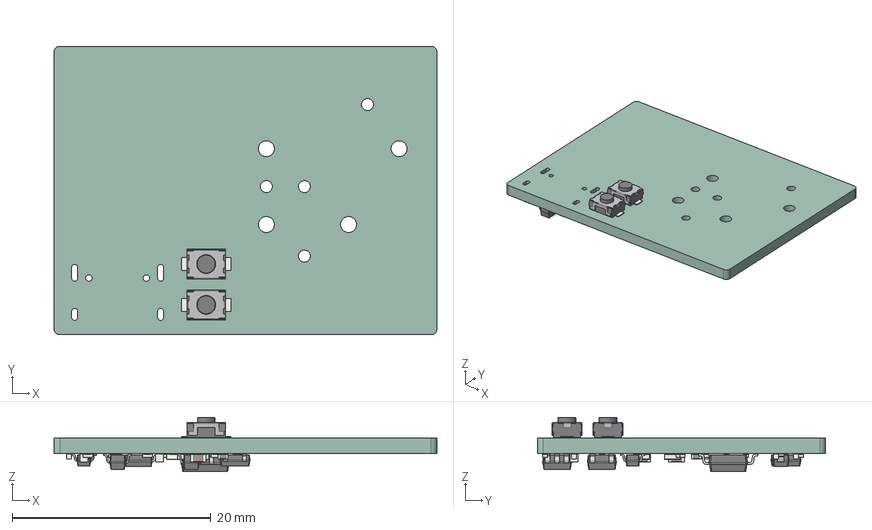
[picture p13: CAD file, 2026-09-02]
production_mini/pl60c_dmx_mini.step
38.5 x 29.0 x 5.43 mm
SW_SPST_TS-1088-xR020 x 2
C_0603_1608Metric x 3
R_1206_3216Metric
D_SOD-123
R_0402_1005Metric x 9
SOT-23-5
C_0402_1005Metric x 5
SOT-23 x 2
Fuse_1206_3216Metric
SOIC-8_3.9x4.9mm_P1.27mm
SOT-23-6
pl60c_dmx_mini_PCB

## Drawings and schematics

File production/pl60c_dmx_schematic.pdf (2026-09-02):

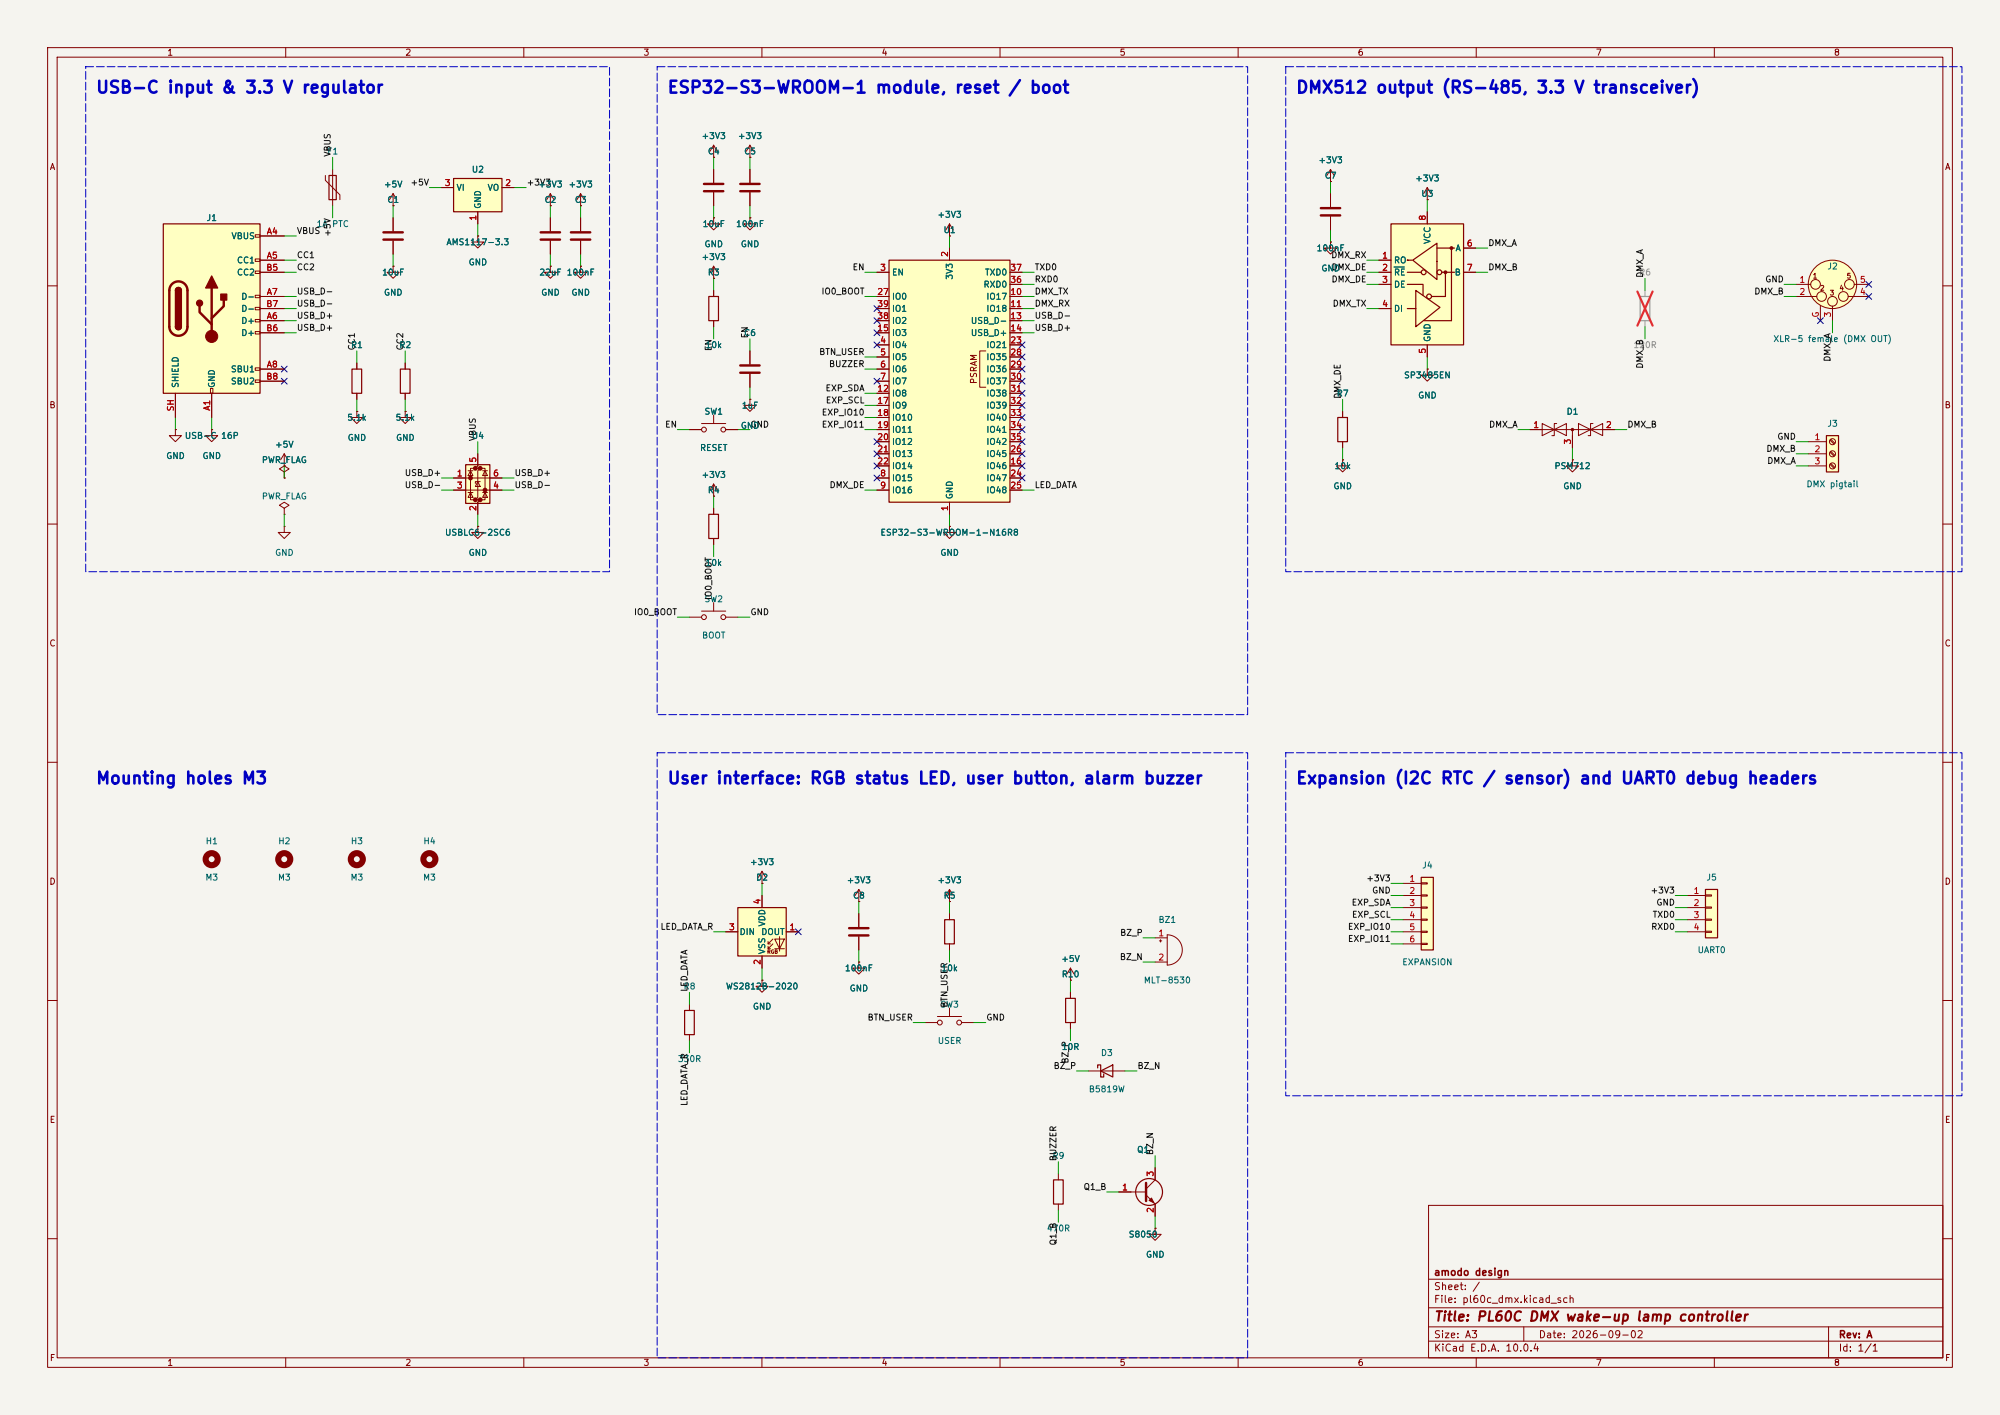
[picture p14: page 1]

amodo design
Sheet: /
File: pl60c_dmx.kicad_sch
Title: PL60C DMX wake-up lamp controller

Size: A3 | Rev: A | F Date: 2026-09-02
KiCad E.D.A. 10.0.4 | Id: 1/1

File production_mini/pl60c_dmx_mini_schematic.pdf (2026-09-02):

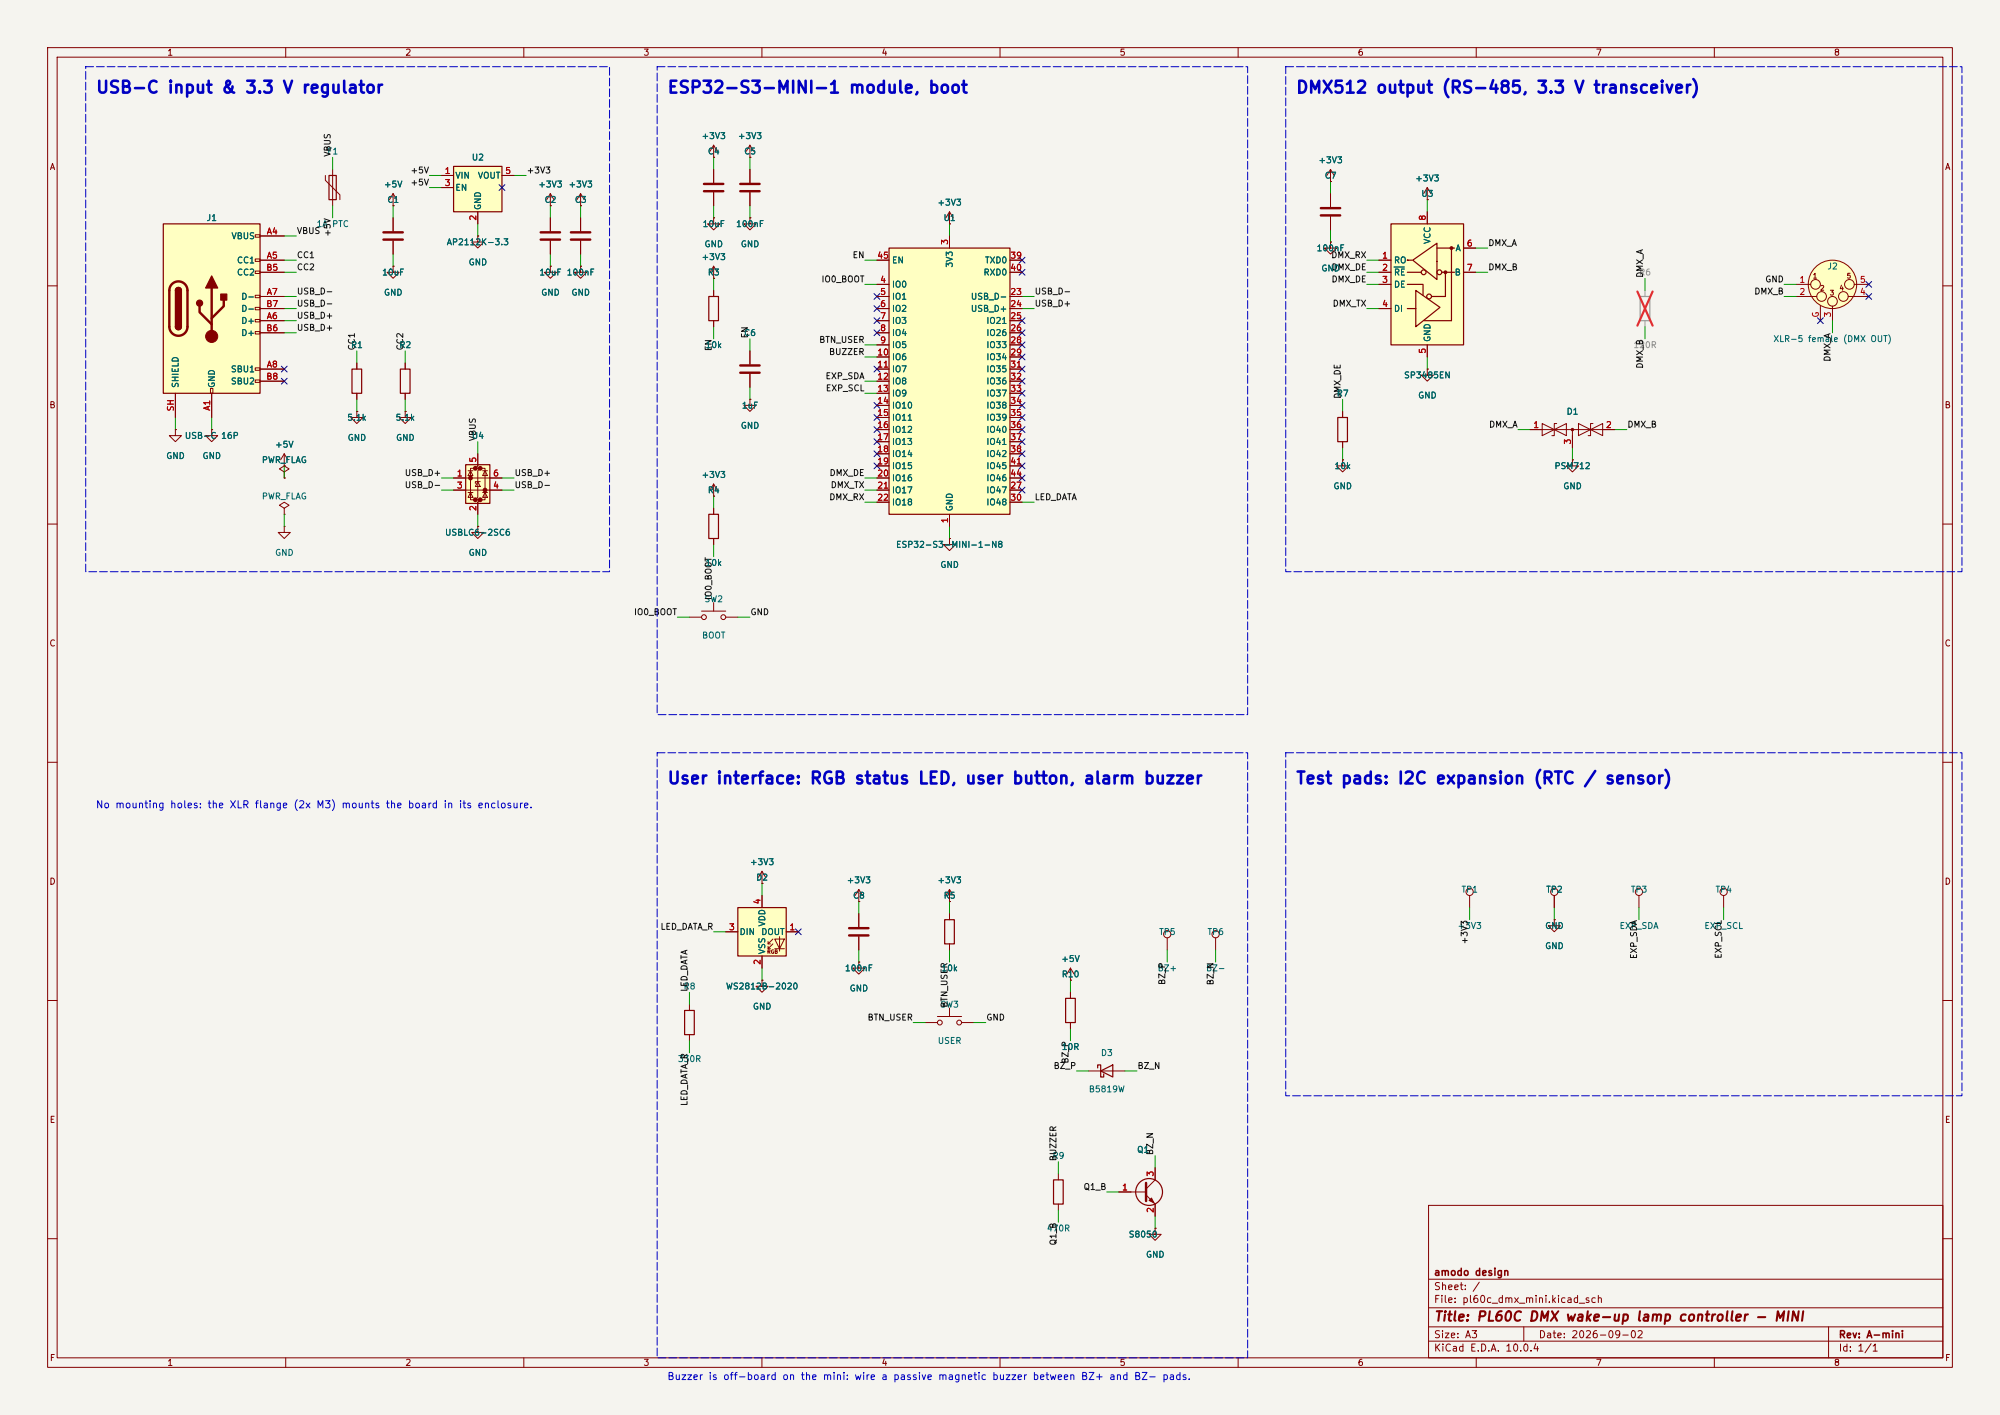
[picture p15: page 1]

No mounting holes: the XLR flange (2x M3) mounts the board in its enclosure.

amodo design
Sheet: /
File: pl60c_dmx_mini.kicad_sch
Title: PL60C DMX wake-up lamp controller - MINI

Size: A3 | Rev: A-mini
KiCad E.D.A. 10.0.4 | Id: 1/1 | F Date: 2026-09-02

Buzzer is off-board on the mini: wire a passive magnetic buzzer between BZ+ and BZ- pads.

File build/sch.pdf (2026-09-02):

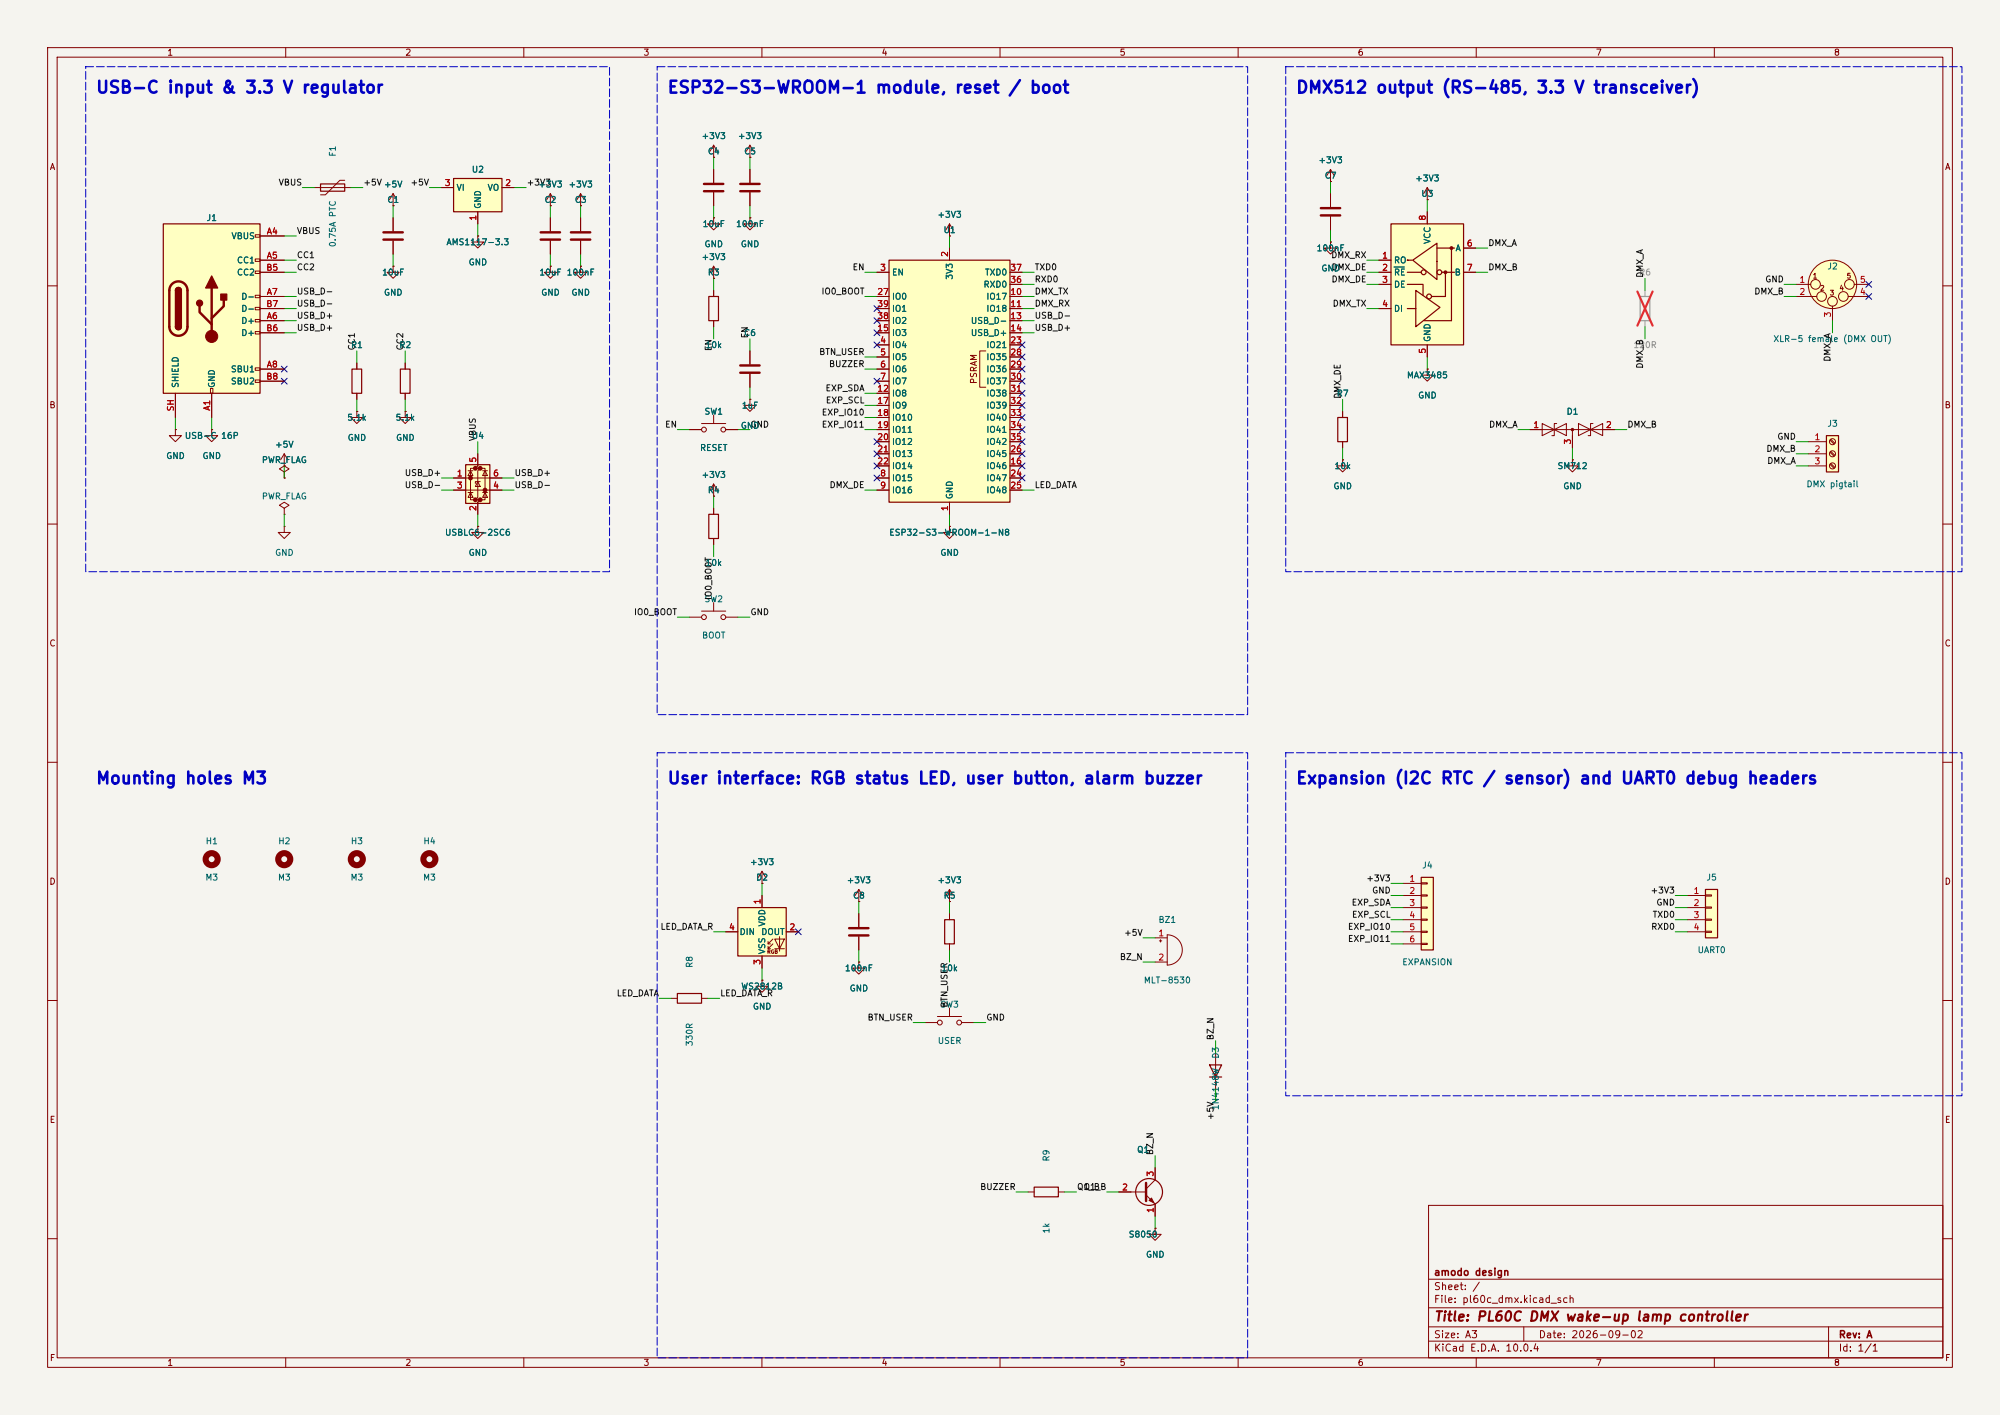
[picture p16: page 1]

User interface: RGB status LED, user button, alarm buzzer

Expansion (I2C RTC / sensor) and UART0 debug headers

amodo design
Sheet: /
File: pl60c_dmx.kicad_sch
Title: PL60C DMX wake-up lamp controller

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

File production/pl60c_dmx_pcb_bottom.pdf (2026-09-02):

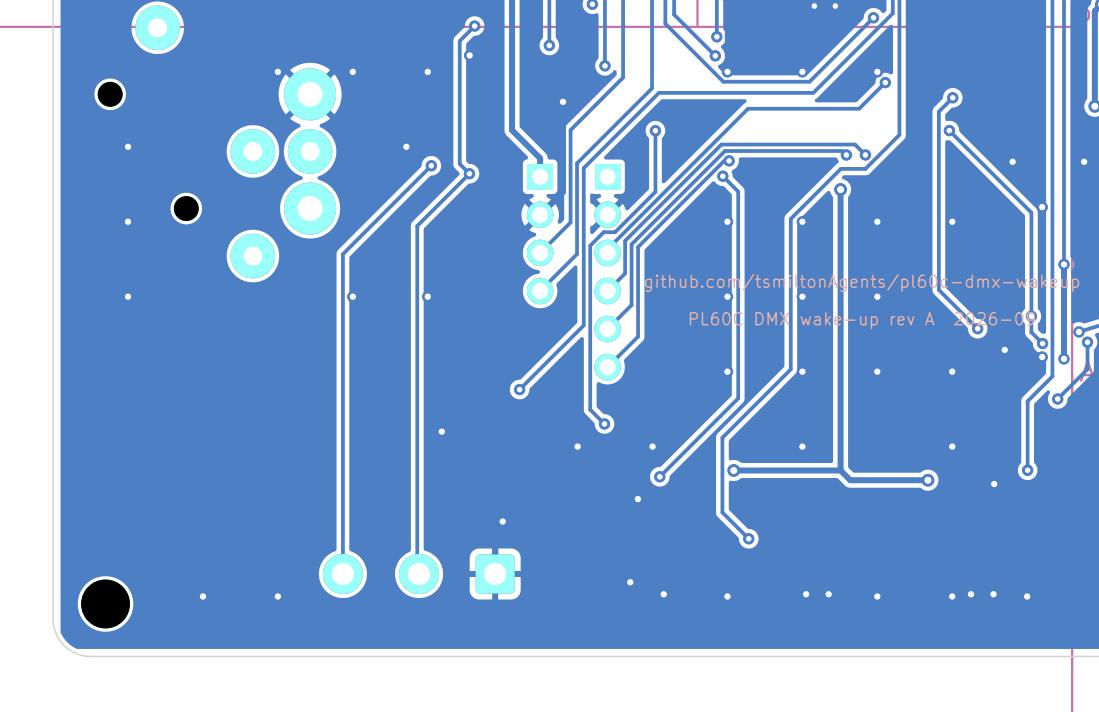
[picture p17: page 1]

Size: A4 | Rev:
KiCad E.D.A. 10.0.4 | Id: 1/1

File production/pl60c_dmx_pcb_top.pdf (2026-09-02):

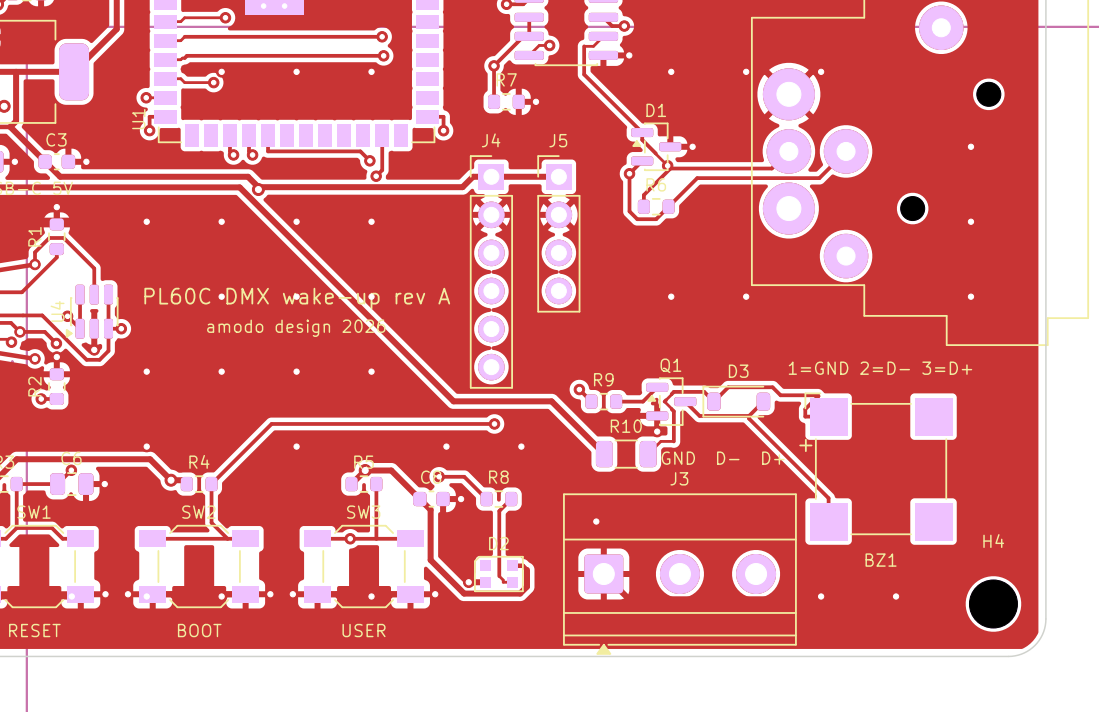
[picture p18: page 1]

Size: A4 | Rev:
KiCad E.D.A. 10.0.4 | Id: 1/1

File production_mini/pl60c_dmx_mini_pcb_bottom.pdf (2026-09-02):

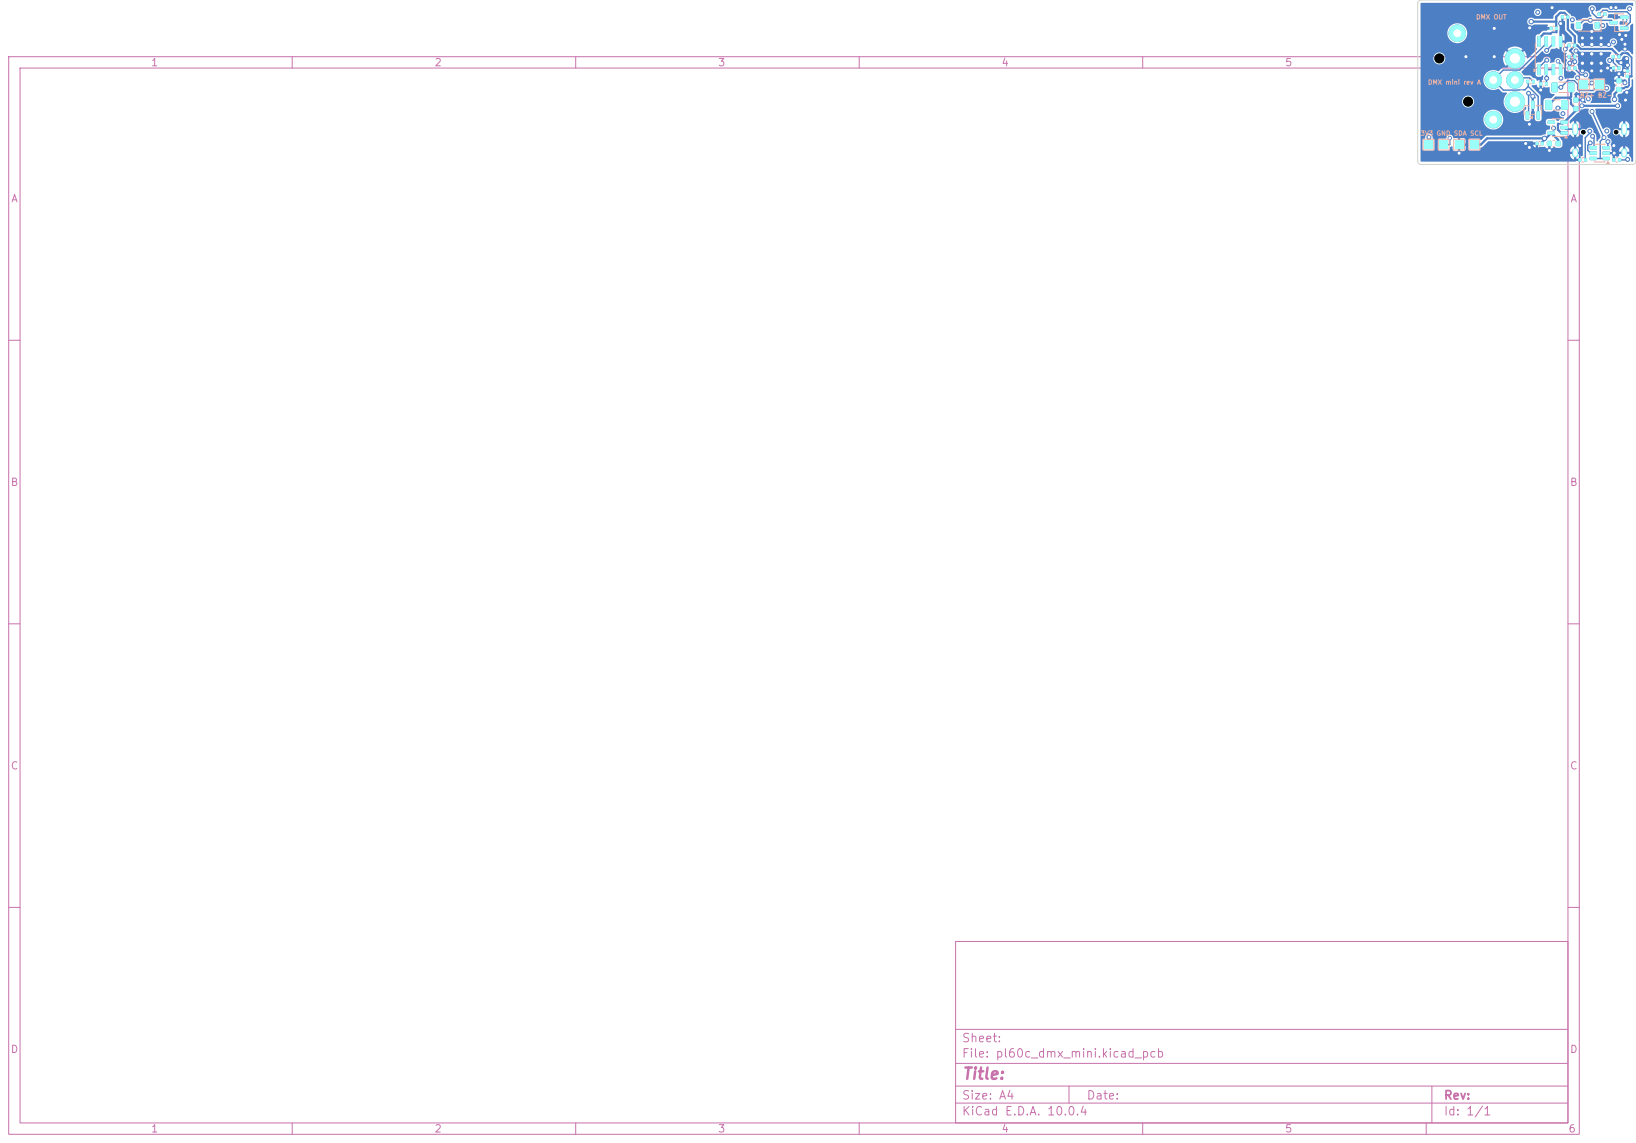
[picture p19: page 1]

DMX OUT DMX mini rev A 3V3 GND SDA SCL

Size: A4 | Rev:
KiCad E.D.A. 10.0.4 | Id: 1/1

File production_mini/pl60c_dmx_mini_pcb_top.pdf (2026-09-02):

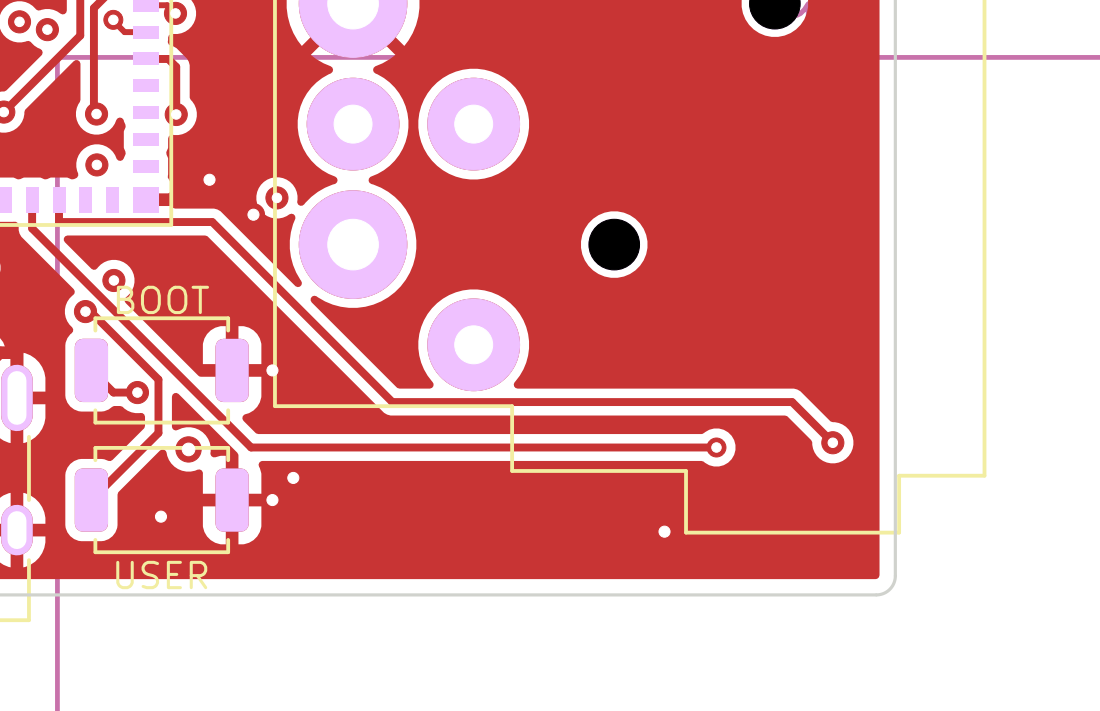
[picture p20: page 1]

Size: A4 | Rev:
KiCad E.D.A. 10.0.4 | Id: 1/1

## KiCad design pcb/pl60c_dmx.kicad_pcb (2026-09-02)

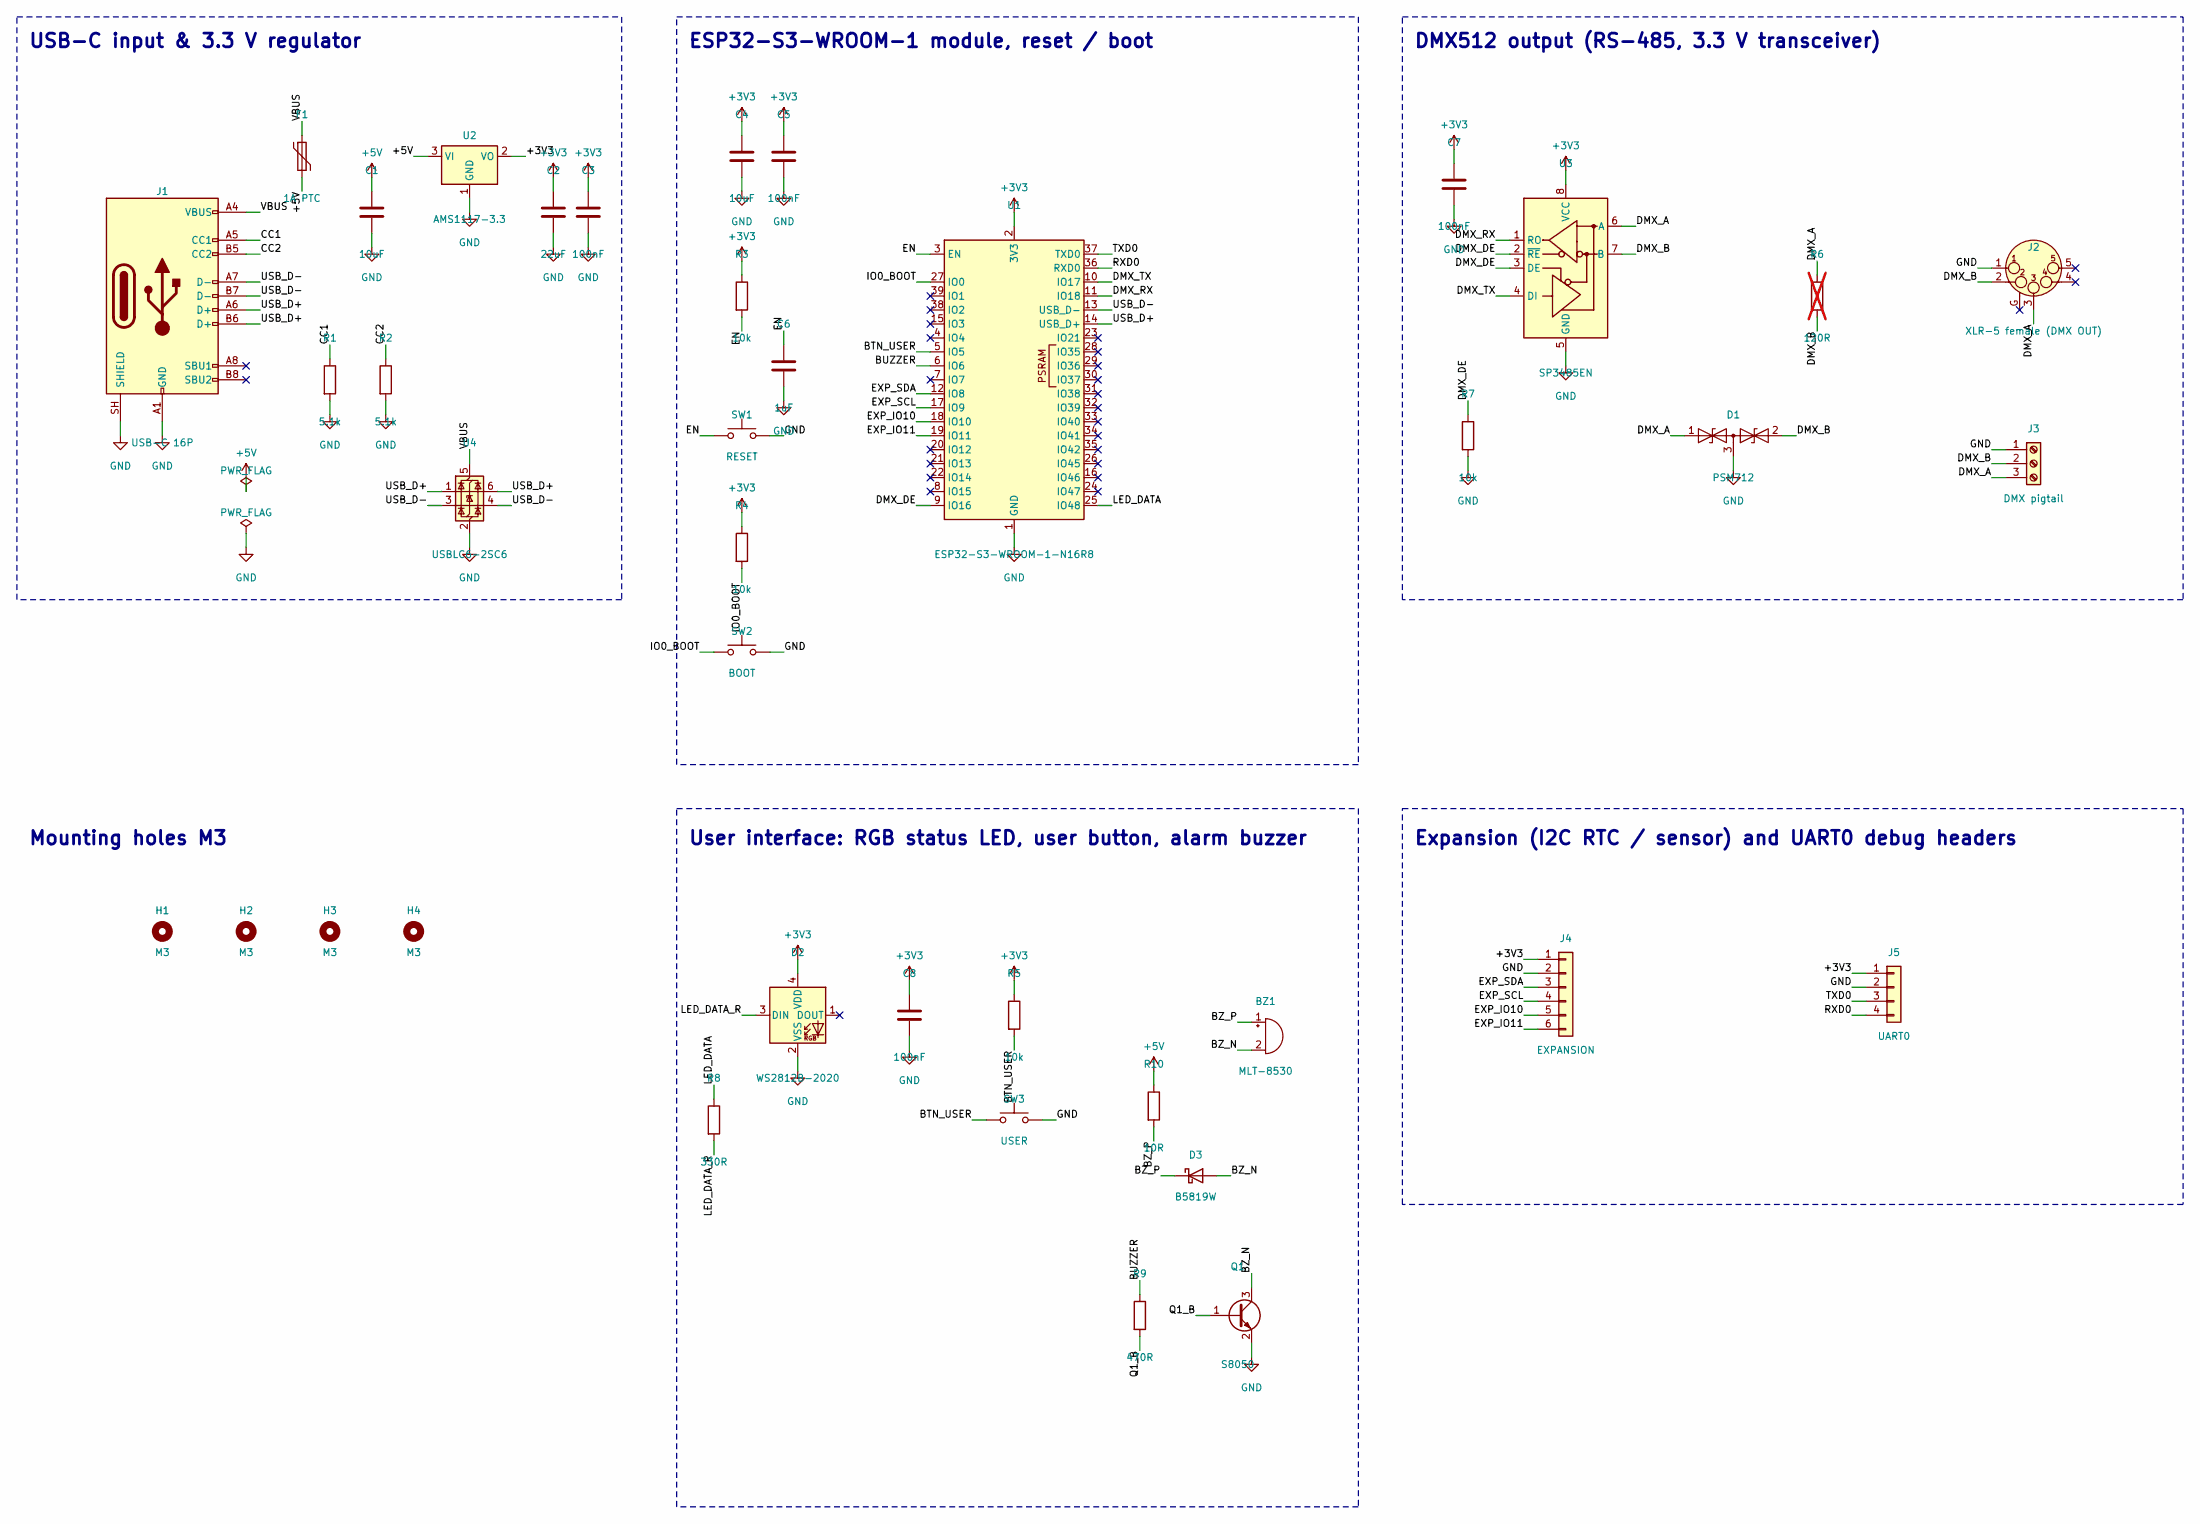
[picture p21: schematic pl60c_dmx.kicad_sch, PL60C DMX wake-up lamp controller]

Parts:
BZ1: MLT-8530; MagneticBuzzer_CUI_CMT-8504-100-SMT; MPN MLT-8530; LCSC C94599
C1, C4: 10uF; C_0805_2012Metric; LCSC C15850
C2: 22uF; C_0805_2012Metric; LCSC C45783
C3, C5, C7, C8: 100nF; C_0603_1608Metric; LCSC C14663
C6: 1uF; C_0805_2012Metric; MPN CL21B105KBFNNNE; LCSC C28323
D1: PSM712; SOT-23; MPN PSM712-LF-T7; LCSC C32677
D2: WS2812B-2020; LED_WS2812B-2020_PLCC4_2.0x2.0mm; MPN WS2812B-2020-V6; LCSC C52917434
D3: B5819W; D_SOD-123; MPN B5819W SL; LCSC C8598
F1: 1A PTC; Fuse_1206_3216Metric; MPN BSMD1206-100-30V; LCSC C5358568
H1, H2, H3, H4: M3; MountingHole_3.2mm_M3
J1: USB-C 16P; USB_C_Receptacle_HRO_TYPE-C-31-M-12; MPN TYPE-C-31-M-12; LCSC C165948
J2: XLR-5 female (DMX OUT); Jack_XLR_Neutrik_NC5FAH_Horizontal; MPN NC5FAH; LCSC C368501
J3: DMX pigtail; TerminalBlock_Phoenix_MKDS-1,5-3-5.08_1x03_P5.08mm_Horizont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; MPN KF128-5.08-3P-AA; LCSC C474953
J4: EXPANSION; PinHeader_1x06_P2.54mm_Vertical; MPN 2.54-1x6P; LCSC C37208
J5: UART0; PinHeader_1x04_P2.54mm_Vertical; MPN B-2100S04P-A110; LCSC C124378
Q1: S8050; SOT-23; MPN S8050; LCSC C2146
R1, R2: 5.1k; R_0603_1608Metric; LCSC C23186
R3, R4, R5, R7: 10k; R_0603_1608Metric; LCSC C25804
R6: 120R; R_0603_1608Metric; LCSC C22787; not fitted
R8: 330R; R_0603_1608Metric; LCSC C23138
R9: 470R; R_0603_1608Metric; LCSC C23179
R10: 10R; R_1206_3216Metric; LCSC C17903
SW1: RESET; SW_SPST_SKQG_WithStem; MPN TS-1187A-B-A-B; LCSC C318884
SW2: BOOT; SW_SPST_SKQG_WithStem; MPN TS-1187A-B-A-B; LCSC C318884
SW3: USER; SW_SPST_SKQG_WithStem; MPN TS-1187A-B-A-B; LCSC C318884
U1: ESP32-S3-WROOM-1-N16R8; ESP32-S3-WROOM-1; MPN ESP32-S3-WROOM-1-N16R8; LCSC C2913202
U2: AMS1117-3.3; SOT-223-3_TabPin2; MPN AMS1117-3.3; LCSC C6186
U3: SP3485EN; SOIC-8_3.9x4.9mm_P1.27mm; MPN SP3485EN-L/TR; LCSC C8963
U4: USBLC6-2SC6; SOT-23-6; MPN USBLC6-2SC6; LCSC C7519

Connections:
+3V3: C2.1, C3.1, C4.1, C5.1, C7.1, C8.1, D2.4 (VDD), J4.1, J5.1, R3.1, R4.1, R5.1, U1.2 (3V3), U2.2 (VO), U3.8 (VCC)
+5V: C1.1, F1.2, R10.1, U2.3 (VI)
BTN_USER: R5.2, SW3.1, U1.5 (IO5)
BUZZER: R9.1, U1.6 (IO6)
BZ_N: BZ1.2 (-), D3.2 (A), Q1.3 (C)
BZ_P: BZ1.1 (+), D3.1 (K), R10.2
CC1: J1.A5 (CC1), R1.1
CC2: J1.B5 (CC2), R2.1
DMX_A: D1.1 (A1), J2.3, J3.3, R6.1, U3.6 (A)
DMX_B: D1.2 (A2), J2.2, J3.2, R6.2, U3.7 (B)
DMX_DE: R7.1, U1.9 (IO16), U3.2 (~RE), U3.3 (DE)
DMX_RX: U1.11 (IO18), U3.1 (RO)
DMX_TX: U1.10 (IO17), U3.4 (DI)
EN: C6.1, R3.2, SW1.1, U1.3 (EN)
EXP_IO10: J4.5, U1.18 (IO10)
EXP_IO11: J4.6, U1.19 (IO11)
EXP_SCL: J4.4, U1.17 (IO9)
EXP_SDA: J4.3, U1.12 (IO8)
GND: C1.2, C2.2, C3.2, C4.2, C5.2, C6.2, C7.2, C8.2, D1.3 (common), D2.2 (VSS), J1.A1 (GND), J1.A12 (GND), J1.B1 (GND), J1.B12 (GND), J1.SH (SHIELD), J2.1, J3.1, J4.2, J5.2, Q1.2 (E), R1.2, R2.2, R7.2, SW1.2, SW2.2, SW3.2, U1.1 (GND), U1.40 (GND), U1.41 (GND), U2.1 (GND), U3.5 (GND), U4.2 (GND)
IO0_BOOT: R4.2, SW2.1, U1.27 (IO0)
LED_DATA: R8.1, U1.25 (IO48)
LED_DATA_R: D2.3 (DIN), R8.2
Q1_B: Q1.1 (B), R9.2
RXD0: J5.4, U1.36 (RXD0)
TXD0: J5.3, U1.37 (TXD0)
USB_D+: J1.A6 (D+), J1.B6 (D+), U1.14 (USB_D+), U4.1 (I/O1), U4.6 (I/O1)
USB_D-: J1.A7 (D-), J1.B7 (D-), U1.13 (USB_D-), U4.3 (I/O2), U4.4 (I/O2)
VBUS: F1.1, J1.A4 (VBUS), J1.A9 (VBUS), J1.B4 (VBUS), J1.B9 (VBUS), U4.5 (VBUS)

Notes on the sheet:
USB-C input & 3.3 V regulator
ESP32-S3-WROOM-1 module, reset / boot
DMX512 output (RS-485, 3.3 V transceiver)
User interface: RGB status LED, user button, alarm buzzer
Expansion (I2C RTC / sensor) and UART0 debug headers
Mounting holes M3

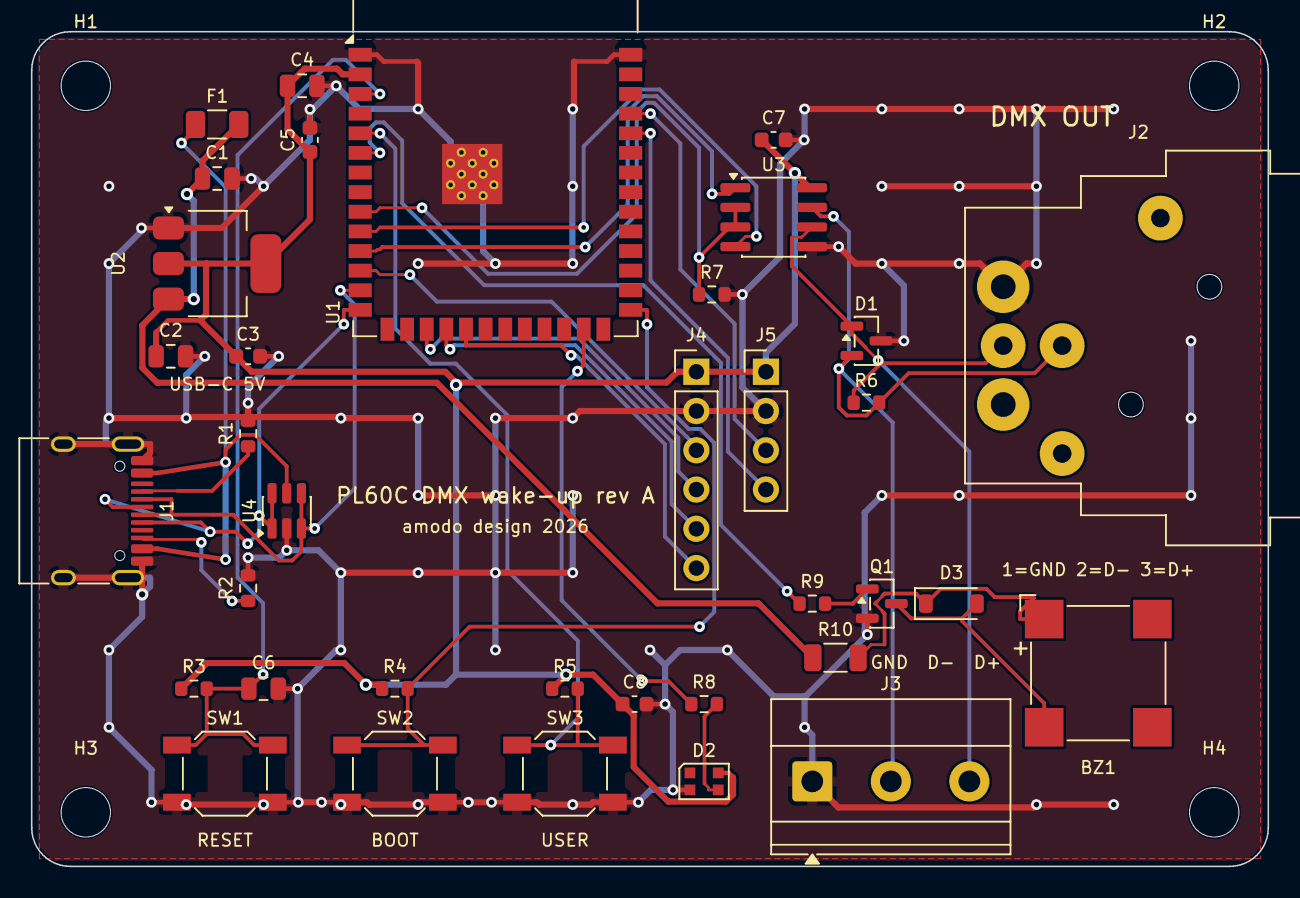
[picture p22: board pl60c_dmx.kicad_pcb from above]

Board: 2 copper layers, 80.0 x 54.0 mm, 40 parts (0 on the bottom side), 28 nets.

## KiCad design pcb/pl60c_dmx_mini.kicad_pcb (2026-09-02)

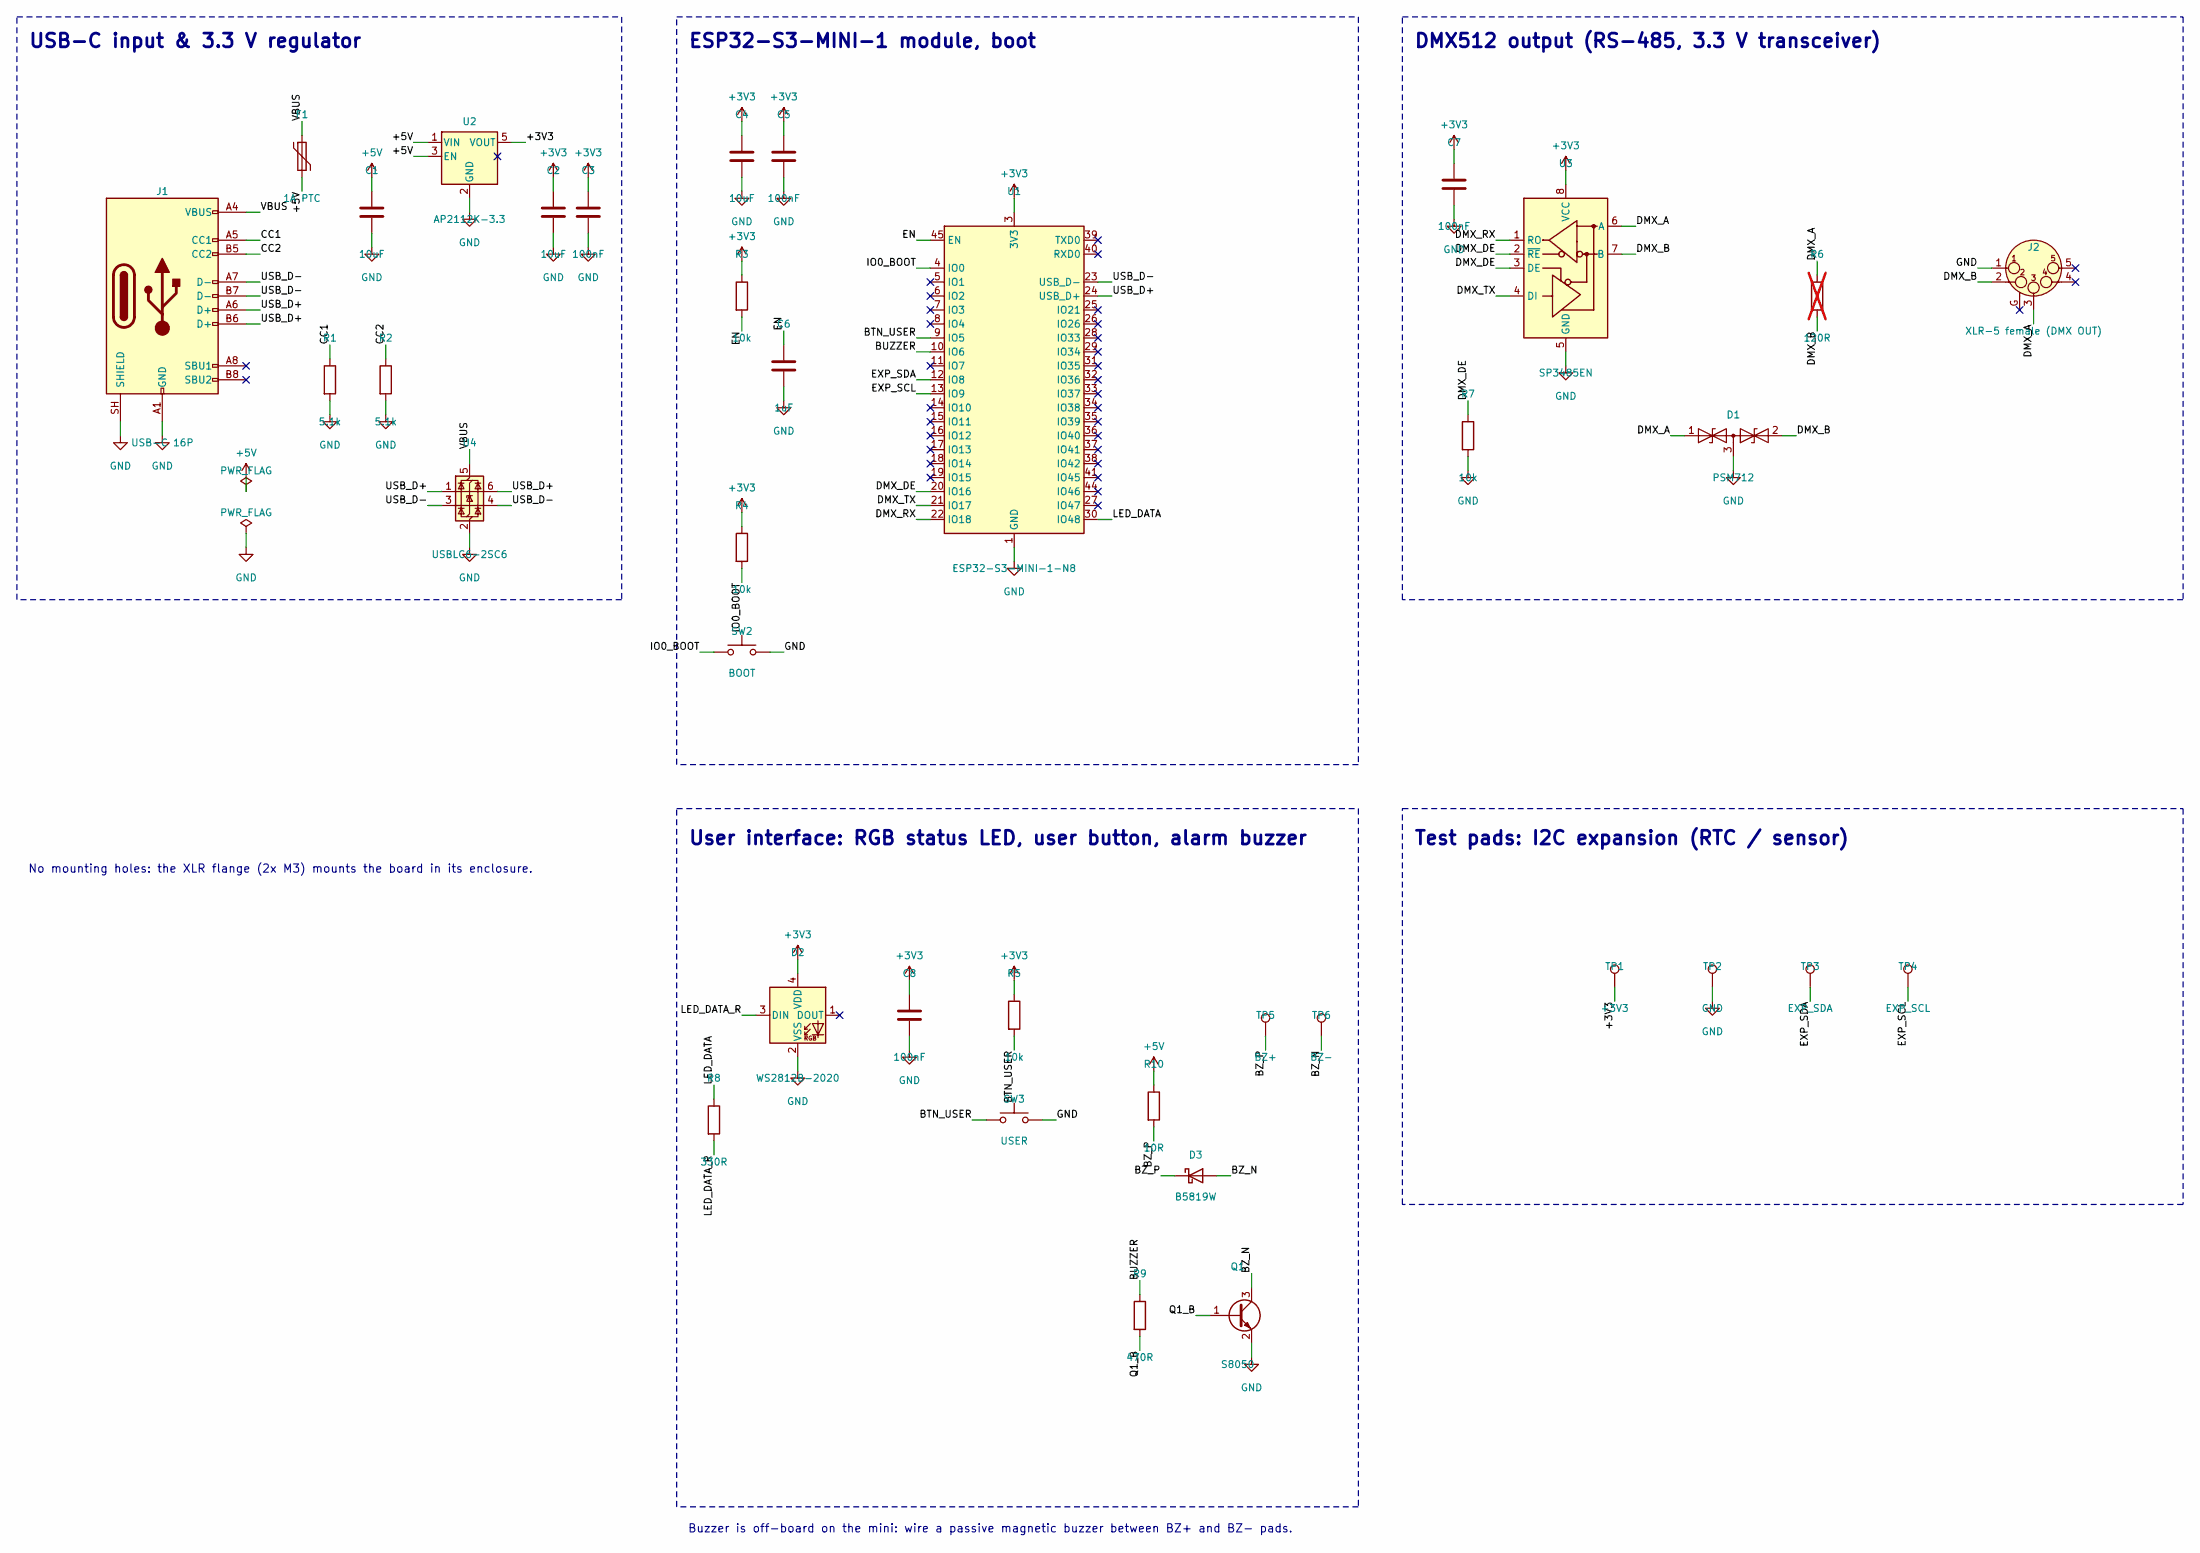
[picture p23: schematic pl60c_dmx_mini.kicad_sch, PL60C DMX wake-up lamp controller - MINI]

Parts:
C1, C2, C4: 10uF; C_0603_1608Metric; LCSC C19702
C3, C5, C7, C8: 100nF; C_0402_1005Metric; LCSC C1525
C6: 1uF; C_0402_1005Metric; LCSC C52923
D1: PSM712; SOT-23; MPN PSM712-LF-T7; LCSC C32677
D2: WS2812B-2020; LED_WS2812B-2020_PLCC4_2.0x2.0mm; MPN WS2812B-2020-V6; LCSC C52917434
D3: B5819W; D_SOD-123; MPN B5819W SL; LCSC C8598
F1: 1A PTC; Fuse_1206_3216Metric; MPN BSMD1206-100-30V; LCSC C5358568
J1: USB-C 16P; USB_C_Receptacle_HRO_TYPE-C-31-M-12; MPN TYPE-C-31-M-12; LCSC C165948
J2: XLR-5 female (DMX OUT); Jack_XLR_Neutrik_NC5FAH_Horizontal; MPN NC5FAH; LCSC C368501
Q1: S8050; SOT-23; MPN S8050; LCSC C2146
R1, R2: 5.1k; R_0402_1005Metric; LCSC C25905
R3, R4, R5, R7: 10k; R_0402_1005Metric; LCSC C25744
R6: 120R; R_0402_1005Metric; LCSC C25079; not fitted
R8: 330R; R_0402_1005Metric; LCSC C25104
R9: 470R; R_0402_1005Metric; LCSC C25117
R10: 10R; R_1206_3216Metric; LCSC C17903
SW2: BOOT; SW_SPST_TS-1088-xR020; MPN TS-1088-AR02016; LCSC C720477
SW3: USER; SW_SPST_TS-1088-xR020; MPN TS-1088-AR02016; LCSC C720477
TP1: +3V3; TestPoint_Pad_1.5x1.5mm
TP2: GND; TestPoint_Pad_1.5x1.5mm
TP3: EXP_SDA; TestPoint_Pad_1.5x1.5mm
TP4: EXP_SCL; TestPoint_Pad_1.5x1.5mm
TP5: BZ+; TestPoint_Pad_1.5x1.5mm
TP6: BZ-; TestPoint_Pad_1.5x1.5mm
U1: ESP32-S3-MINI-1-N8; ESP32-S2-MINI-1; MPN ESP32-S3-MINI-1-N8; LCSC C2913206
U2: AP2112K-3.3; SOT-23-5; MPN AP2112K-3.3TRG1; LCSC C51118
U3: SP3485EN; SOIC-8_3.9x4.9mm_P1.27mm; MPN SP3485EN-L/TR; LCSC C8963
U4: USBLC6-2SC6; SOT-23-6; MPN USBLC6-2SC6; LCSC C7519

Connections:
+3V3: C2.1, C3.1, C4.1, C5.1, C7.1, C8.1, D2.4 (VDD), R3.1, R4.1, R5.1, TP1.1, U1.3 (3V3), U2.5 (VOUT), U3.8 (VCC)
+5V: C1.1, F1.2, R10.1, U2.1 (VIN), U2.3 (EN)
BTN_USER: R5.2, SW3.1, U1.9 (IO5)
BUZZER: R9.1, U1.10 (IO6)
BZ_N: D3.2 (A), Q1.3 (C), TP6.1
BZ_P: D3.1 (K), R10.2, TP5.1
CC1: J1.A5 (CC1), R1.1
CC2: J1.B5 (CC2), R2.1
DMX_A: D1.1 (A1), J2.3, R6.1, U3.6 (A)
DMX_B: D1.2 (A2), J2.2, R6.2, U3.7 (B)
DMX_DE: R7.1, U1.20 (IO16), U3.2 (~RE), U3.3 (DE)
DMX_RX: U1.22 (IO18), U3.1 (RO)
DMX_TX: U1.21 (IO17), U3.4 (DI)
EN: C6.1, R3.2, U1.45 (EN)
EXP_SCL: TP4.1, U1.13 (IO9)
EXP_SDA: TP3.1, U1.12 (IO8)
GND: C1.2, C2.2, C3.2, C4.2, C5.2, C6.2, C7.2, C8.2, D1.3 (common), D2.2 (VSS), J1.A1 (GND), J1.A12 (GND), J1.B1 (GND), J1.B12 (GND), J1.SH (SHIELD), J2.1, Q1.2 (E), R1.2, R2.2, R7.2, SW2.2, SW3.2, TP2.1, U1.1 (GND), U1.2 (GND), U1.42 (GND), U1.43 (GND), U1.46 (GND), U1.47 (GND), U1.48 (GND), U1.49 (GND), U1.50 (GND), U1.51 (GND), U1.52 (GND), U1.53 (GND), U1.54 (GND), U1.55 (GND), U1.56 (GND), U1.57 (GND), U1.58 (GND), U1.59 (GND), U1.60 (GND), U1.61 (GND), U1.62 (GND), U1.63 (GND), U1.64 (GND), U1.65 (GND), U2.2 (GND), U3.5 (GND), U4.2 (GND)
IO0_BOOT: R4.2, SW2.1, U1.4 (IO0)
LED_DATA: R8.1, U1.30 (IO48)
LED_DATA_R: D2.3 (DIN), R8.2
Q1_B: Q1.1 (B), R9.2
USB_D+: J1.A6 (D+), J1.B6 (D+), U1.24 (USB_D+), U4.1 (I/O1), U4.6 (I/O1)
USB_D-: J1.A7 (D-), J1.B7 (D-), U1.23 (USB_D-), U4.3 (I/O2), U4.4 (I/O2)
VBUS: F1.1, J1.A4 (VBUS), J1.A9 (VBUS), J1.B4 (VBUS), J1.B9 (VBUS), U4.5 (VBUS)

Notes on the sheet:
USB-C input & 3.3 V regulator
ESP32-S3-MINI-1 module, boot
DMX512 output (RS-485, 3.3 V transceiver)
User interface: RGB status LED, user button, alarm buzzer
Test pads: I2C expansion (RTC / sensor)
No mounting holes: the XLR flange (2x M3) mounts the board in its enclosure.
Buzzer is off-board on the mini: wire a passive magnetic buzzer between BZ+ and BZ- pads.

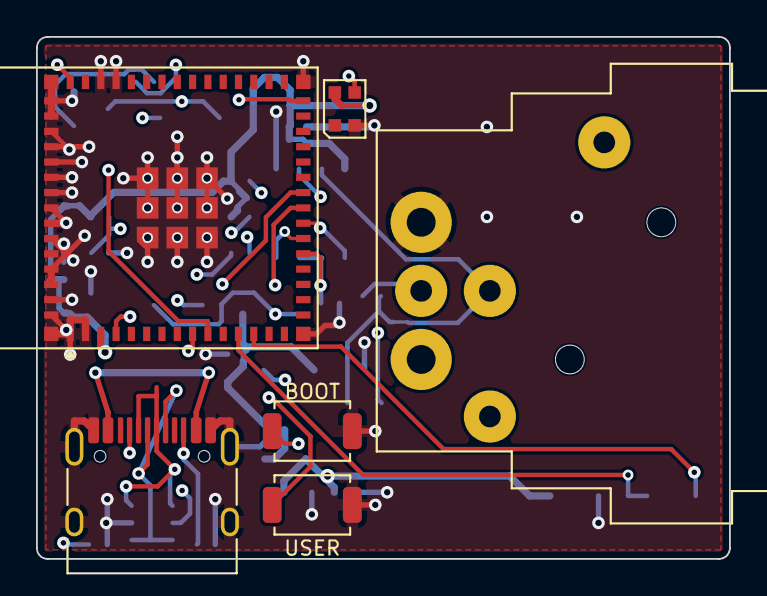
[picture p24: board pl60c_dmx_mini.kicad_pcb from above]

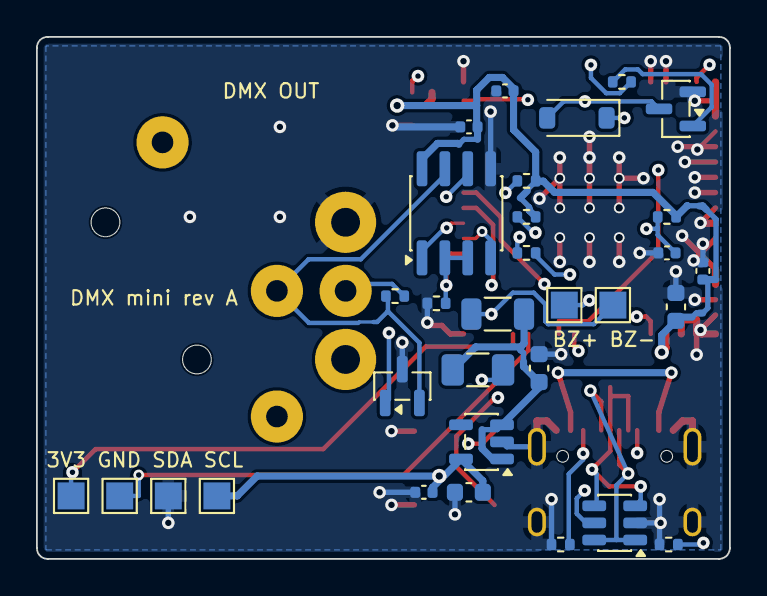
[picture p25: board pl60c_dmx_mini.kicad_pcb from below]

Board: 4 copper layers, 38.5 x 29.0 mm, 37 parts (31 on the bottom side), 24 nets.

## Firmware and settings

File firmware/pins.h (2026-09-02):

/*
 * PL60C DMX wake-up lamp controller - board pin map and DMX constants (rev A).
 * This is the only "firmware" file in this repo: it documents what the hardware expects.
 * Target: ESP32-S3-WROOM-1 (N16R8) on rev A, ESP32-S3-MINI-1 (N8) on the mini: identical GPIO map.
 * Mini differences: no RESET button, no UART0 header, buzzer is external on the BZ+/BZ- pads.  Framework: ESP-IDF or Arduino-ESP32; DMX via the esp_dmx library.
 */
#pragma once

/* ---- DMX512 transmitter (SP3485EN RS-485, half duplex) ---- */
#define PIN_DMX_TX      17   /* UART TX  -> SP3485 DI          (use UART1 / dmx_port 1)        */
#define PIN_DMX_RX      18   /* UART RX  <- SP3485 RO. RO floats while DE=1: enable the internal pull-up */
#define PIN_DMX_DE      16   /* HIGH = drive the line (DE and /RE tied together, 10k pull-down) */

/* ---- USB ---- */
/* GPIO19 = USB D-, GPIO20 = USB D+ : native USB-Serial/JTAG, nothing to configure. */

/* ---- User interface ---- */
#define PIN_BTN_BOOT     0   /* BOOT button, active low (also strapping pin, safe to read after boot) */
#define PIN_BTN_USER     5   /* USER button, active low, 10k pull-up on board (snooze / manual light) */
#define PIN_RGB_LED     48   /* WS2812B data (330 R series), LED powered from 3V3 like the DevKitC   */
#define PIN_BUZZER       6   /* NPN driver, HIGH = coil energised. 2.7 kHz square wave, 50 % duty (10 R series limits coil current) */

/* ---- Expansion header J4 (3V3, GND, SDA, SCL, IO10, IO11); no on-board I2C pull-ups ---- */
#define PIN_EXP_SDA      8
#define PIN_EXP_SCL      9
#define PIN_EXP_IO10    10
#define PIN_EXP_IO11    11

/* ---- UART0 debug header J5 (3V3, GND, TX, RX) ---- */
#define PIN_UART0_TX    43
#define PIN_UART0_RX    44

/* MINI thermal note: the SOT-23-5 LDO relies on Wi-Fi power-save (modem sleep); keep sustained full-power TX short. */

/* ---- DMX512 timing (ANSI E1.11) ---- */
#define DMX_BAUD              250000
#define DMX_BREAK_US             176   /* >= 92 us required, 176 us typical */
#define DMX_MAB_US                12   /* >= 12 us */
#define DMX_START_CODE             0
#define DMX_REFRESH_HZ            44   /* send a full frame at least ~40 Hz; PL60C reported flaky below 44 Hz */
#define DMX_UNIVERSE_SIZE        512

/* ---- Neewer PL60C, fixed personality (DMX start address = channel 1) ---- */
#define PL60C_CH_MODE              1   /* 0-31 CCT, 32-63 HSI, 64-95 FX, 96-127 GEL, 128-159 RGBCW, 160-191 XY */
#define PL60C_CH_INTENSITY         2   /* 0-255 -> 0-100 %                                      */
#define PL60C_CH_CCT               3   /* CCT mode: 0-255 -> 2500-10000 K                       */
#define PL60C_CH_GM                4   /* CCT mode: green/magenta -50 .. +50 (128 = neutral)    */
#define PL60C_MODE_CCT             0
#define PL60C_MODE_HSI            32
#define PL60C_MODE_RGBCW         128
#define PL60C_FOOTPRINT_CHANNELS   9   /* the FX mode uses up to 9 channels; keep the rest zero */

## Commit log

2026-09-02 auto: 2026-09-02 12:44:29
    Claude-Session: https://claude.ai/code/session_01WsrVZb94LwbHVAmBvsSTfn
    [smoke.dsn, smoke.kicad_pcb]
2026-09-02 auto: 2026-09-02 12:46:31
    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
    [smoke.dsn, smoke.kicad_pcb]
2026-09-02 auto: 2026-09-02 12:50:32
    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
    [drop_label.kicad_sch, drop_no_connect.kicad_sch, drop_rectangle.kicad_sch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]
2026-09-02 auto: 2026-09-02 12:52:34
    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
    [pl60c_dmx.kicad_sch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]
2026-09-02 auto: 2026-09-02 12:58:38
    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
    [bis_footprint.kicad_pcb, bis_gr_arc.kicad_pcb, bis_gr_line.kicad_pcb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]
2026-09-02 auto: 2026-09-02 13:00:39
    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
    [pl60c_dmx.dsn, pl60c_dmx.kicad_pcb, unrouted.kicad_pcb]
2026-09-02 auto: 2026-09-02 13:04:43
    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
    [pl60c_dmx.kicad_sch]
2026-09-02 auto: 2026-09-02 13:06:45
    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
    [pl60c_dmx.dsn, pl60c_dmx.kicad_pcb, pl60c_dmx.kicad_sch]
2026-09-02 auto: 2026-09-02 13:08:46
    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
    [pl60c_dmx.dsn, pl60c_dmx.kicad_pcb]
2026-09-02 auto: 2026-09-02 13:10:48
    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
    [pl60c_dmx.kicad_pcb]
2026-09-02 auto: 2026-09-02 13:12:50
    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
    [pl60c_dmx.dsn, pl60c_dmx.kicad_pcb]
2026-09-02 auto: 2026-09-02 13:14:52
    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
    [pl60c_dmx.dsn, pl60c_dmx.kicad_pcb]
2026-09-02 auto: 2026-09-02 13:16:54
    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
    [pl60c_dmx.dsn, pl60c_dmx.kicad_pcb]
2026-09-02 auto: 2026-09-02 13:18:56
    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
    [pl60c_dmx.dsn, pl60c_dmx.kicad_pcb]
2026-09-02 auto: 2026-09-02 13:20:58
    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
    [pl60c_dmx-B_Cu.gbl, pl60c_dmx-B_Mask.gbs, pl60c_dmx-B_Paste.gbp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]
2026-09-02 auto: 2026-09-02 13:23:01
    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
    [pl60c_dmx-B_Cu.gbl, pl60c_dmx-B_Mask.gbs, pl60c_dmx-B_Paste.gbp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]
2026-09-02 auto: 2026-09-02 13:25:05
    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
    [pl60c_dmx-B_Cu.gbl, pl60c_dmx-B_Mask.gbs, pl60c_dmx-B_Paste.gbp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]
2026-09-02 auto: 2026-09-02 13:27:07
    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
    [pl60c_dmx.dsn, pl60c_dmx.kicad_pcb, pl60c_dmx.kicad_sch]
2026-09-02 PL60C DMX wake-up controller rev A: verified design, JLCPCB production files, docs
    - ESP32-S3-WROOM-1 + SP3485EN DMX512 transmitter, XLR-5 out, USB-C power
    - generated schematic/PCB (KiCad 10), Freerouting autoroute, ERC/DRC clean
    - Gerbers, JLCPCB BOM + CPL, LCSC stock-verified parts, README + pin map
    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
    [pl60c_dmx-B_Cu.gbl, pl60c_dmx-B_Mask.gbs, pl60c_dmx-B_Paste.gbp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]
2026-09-02 auto: 2026-09-02 13:40:12
    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
    [pl60c_dmx-B_Cu.gbl, pl60c_dmx-B_Mask.gbs, pl60c_dmx-B_Paste.gbp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]
2026-09-02 auto: 2026-09-02 13:42:45
    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
    [pl60c_dmx_mini.kicad_pcb, pl60c_dmx_mini.kicad_sch]
2026-09-02 auto: 2026-09-02 13:50:15
    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
    [pl60c_dmx_mini.kicad_pcb, pl60c_dmx_mini.kicad_sch]
2026-09-02 auto: 2026-09-02 13:52:17
    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
    [pl60c_dmx_mini.kicad_pcb]
2026-09-02 auto: 2026-09-02 13:54:19
    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
    [pl60c_dmx_mini.kicad_pcb]
2026-09-02 auto: 2026-09-02 13:56:20
    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
    [pl60c_dmx_mini.kicad_pcb]
2026-09-02 auto: 2026-09-02 13:58:22
    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
    [pl60c_dmx_mini.kicad_pcb, pl60c_dmx_mini.kicad_sch]
2026-09-02 auto: 2026-09-02 14:00:24
    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
    [pl60c_dmx_mini.kicad_pcb]
2026-09-02 auto: 2026-09-02 14:02:26
    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
    [pl60c_dmx_mini.kicad_pcb, pl60c_dmx_mini.kicad_sch]
2026-09-02 auto: 2026-09-02 14:09:56
    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
    [pl60c_dmx_mini.kicad_pcb, pl60c_dmx_mini.kicad_sch]
2026-09-02 auto: 2026-09-02 14:11:58
    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
    [pl60c_dmx_mini.kicad_pcb]
2026-09-02 auto: 2026-09-02 14:14:01
    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
    [pl60c_dmx_mini.kicad_pcb, pl60c_dmx_mini.kicad_sch]
2026-09-02 auto: 2026-09-02 14:16:03
    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
    [pl60c_dmx_mini.kicad_pcb, pl60c_dmx_mini.kicad_sch]
2026-09-02 auto: 2026-09-02 14:18:05
    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
    [pl60c_dmx_mini.kicad_pcb, pl60c_dmx_mini.kicad_sch]
2026-09-02 auto: 2026-09-02 14:20:07
    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
    [pl60c_dmx_mini.kicad_pcb]
2026-09-02 auto: 2026-09-02 14:22:09
    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
    [pl60c_dmx_mini.kicad_pcb, pl60c_dmx_mini.kicad_sch]
2026-09-02 auto: 2026-09-02 14:24:11
    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
    [pl60c_dmx_mini.kicad_pcb]
2026-09-02 auto: 2026-09-02 14:26:12
    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
    [pl60c_dmx-B_Cu.gbl, pl60c_dmx-B_Mask.gbs, pl60c_dmx-B_Paste.gbp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]
2026-09-02 Add MINI variant: 38.5x29 mm, 4-layer, double-sided, ESP32-S3-MINI-1, XLR kept
    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
    [pl60c_dmx.step, pl60c_dmx_bom_jlcpcb.csv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]
2026-09-02 auto: 2026-09-02 14:45:57
    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
    [pl60c_dmx_mini.kicad_pcb, pl60c_dmx_mini.kicad_sch]
2026-09-02 auto: 2026-09-02 14:48:00
    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
    [pl60c_dmx-B_Cu.gbl, pl60c_dmx-B_Mask.gbs, pl60c_dmx-B_Paste.gbp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]
2026-09-02 auto: 2026-09-02 14:50:03
    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
    [pl60c_dmx_mini.kicad_pcb]
2026-09-02 auto: 2026-09-02 14:52:05
    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
    [pl60c_dmx_mini.kicad_pcb, pl60c_dmx_mini.kicad_sch]
2026-09-02 auto: 2026-09-02 14:54:07
    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
    [pl60c_dmx_mini-B_Cu.gbl, pl60c_dmx_mini-B_Mask.gbs, pl60c_dmx_mini-B_Paste.gbp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]
2026-09-02 auto: 2026-09-02 14:56:10
    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
    [pl60c_dmx-B_Cu.gbl, pl60c_dmx-B_Mask.gbs, pl60c_dmx-B_Paste.gbp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]
2026-09-02 Design review: fix SOT-23 S8050 pinout, 3.3 V-rated RGB LED, buzzer series resistor and base drive, 22uF LDO cap, mini PTC/decoupling; add docs/REVIEW.md
    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
    [pl60c_dmx.step]
